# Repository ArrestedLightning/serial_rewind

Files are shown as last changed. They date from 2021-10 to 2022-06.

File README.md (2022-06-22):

# Serial Rewind

Serial Rewind Logo

This project provides an internal serial port to certain PowerPC Macintosh computers that shipped without one built in.  This is accomplished by replacing the internal modem, similar to the GeeThree StealthPort, the Griffin gPort, and Alex Hixon's Jamport.

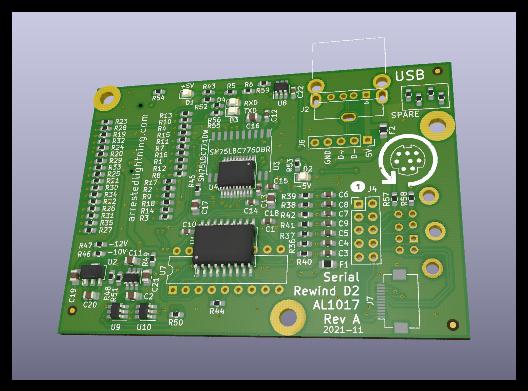
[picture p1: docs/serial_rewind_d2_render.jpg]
Serial Rewind Board render


This project is a work-in-progress.  Any use of the files here is at your own risk.

The goal is to support most PowerPC G3 and G4 machines.  See the README file in the hardware directory for more information on the status of each variant.

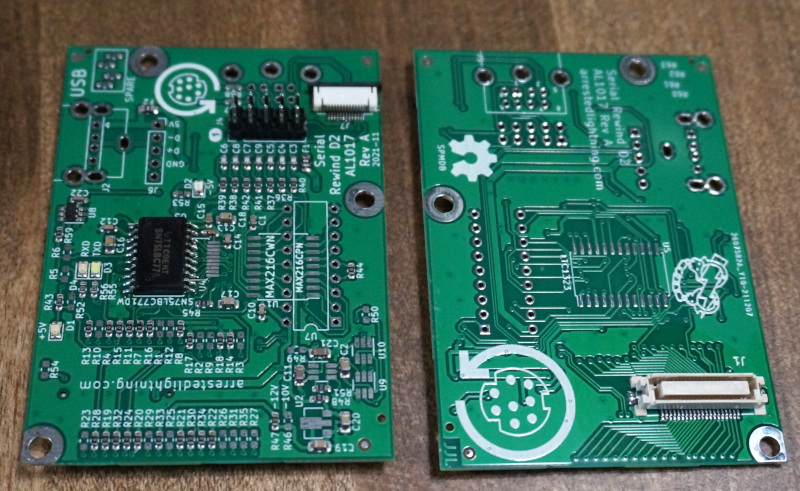
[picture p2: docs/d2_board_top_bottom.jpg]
Serial Rewind Board Picture


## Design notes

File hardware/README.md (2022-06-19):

Serial Rewind Hardware
==========

Serial Rewind Logo

The goal of this project is to eventually support a wide variety of PowerPC Macs.  To do so, a number of different boards are required.  The boards and their statuses are listed below:

|Board|Description|Status|
|-----|---|---|
|d1_g3|Main board ("Dash 1" interface) for tray load iMac G3, B&W Power Mac G3, and PCI Graphics Power Mac G4|Mechanical drawing of board in progress, reverse engineering of schematic not yet started.|
|dash2|Main board ("Dash 2" interface) for a wide variety of Macs: Slot load iMac G3, some iBooks, PowerBook G3, Power Mac G4 & Cube.  All machines except iMac G3 and Cube require an additional board to bring the port out.|Working.  Tested on G4 Cube and G4 MDD.|
|main_mini|Main board for Mac Mini G4, eMac G4, possibly others. | Pinout reverse engineered, schematic in progress. |
|portboard_dt|Port breakout board.  Originally intended for G4 towers.  I believe it would also fit in the iBook G3, but this is not tested. | Electrically functional, layout is a work-in-progress.  The goal was to support both the MDD and earlier G4 machines with the same board, but I don't know if that will be possible. |
|portboard_ffc|Generic port breakout board with flat-flex cable connector. Intended for use with PCI card bracket.| PCB Complete (3D-printed mounting adapter not designed yet)|
|portboard_ribbon|Generic port breakout board with IDC/ribbon cable connector. Intended for use with PCI card bracket.| PCB Complete (3D-printed mounting adapter not designed yet)|| |
|portboard_img4|Port breakout board for iMac G4.  As far as I know, the iMac G4 is the only machine which uses this form factor.| Designed and manufactured, but not yet fit tested. |
|portboard_mdd|Port breakout board for the Power Mac G4 MDD.  This board replaces the MDD's modem port and mounting bracket.  Unfortunately, there's no great way to mount one side of this board.  Since (as far as I know) every MDD comes with a reversible modem port mounting bracket, it seems like it would make more sense to take advantage of that. |Designed and tested.  Eventually this board may be made obsolete by an updated portboard\_dt. |
|portboard_mini|Port breakout board for Mac Mini G4. | Design not started yet.|

All of these boards use components from my [KiCad libraries project](https://github.com/ArrestedLightning/al_kicad_libraries/).  If you work on any of these boards, I would suggest checking out a copy of that project and adding the libraries to your KiCad globals.

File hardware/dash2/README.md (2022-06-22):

# "Dash 2" main board

Dash 2 PCB Render

This is the main board for systems which use a "Dash 2" modem board. This covers a large number of the PowerPC Macs, including the Slot load iMac G3, at least some G3 PowerBooks and iBooks, all Power Mac G4s, and the G4 Cube.  The original Dash 2 modem board supported both an onboard modem port and an external one.  This board also supports both an onboard serial port and an external one.  As far as I know, the onboard port was only used on the slot load iMac G3s and the G4 Cube.  I have tested the onboard port on a G4 cube and it fits perfectly;  I have not yet had the chance to test on an iMac.  All other machines will require an external port breakout board to get the serial port out.

The board is designed around the use of vintage GeoPort chips.  Back in the day, several different chips with roughly equivalent functionality were produced by different manufacturers, but they have all been out of production for years.  At the moment, they seem to be relatively easy to obtain, but that may not necessarily be the case going forward.  Therefore, this board has been designed to support multiple different chips.  All of these vintage chips will require a -5V power supply.  Some can generate their own -5V supply, others require an external -5V supply.  Some Macs provide a negative supply which can be used to produce this; others only provide a positive supply which will then need to be inverted.  This technique will also work on Macs that provide a negative supply and is generally preferred for maximum compatibility.  The board supports a number of different voltage and chip combinations by populating different voltage regulator ICs and jumpers.

The choice to use vintage ICs was a deliberate one; their use of a negative supply is significant.  Although it is possible to produce a working RS-422 serial port using modern ICs (as done in the Jamport), the Mac serial port is actually a unique RS-422/RS232 hybrid design that doesn't really have a modern equivalent as far as I can tell.  Without a negative supply, the voltage output will only be 0-5V in RS232 mode.  While this will work with many recent RS-232 devices, there are a number of vintage devices which really only work well if the RS-232 signal levels can swing negative.  Therefore, for maximum compatibility with vintage devices, there really is no substitute for period-correct transceiver ICs.

The Dash 2 connector also provides signals for a USB port.  This board breaks those signals out to a standard USB type A port, which can be mounted horizontally or vertically.  This could be used (for example) for an internal flash drive or Bluetooth adapter.

More information on possible configurations is detailed on the schematic.  Feel free to open an issue if anything is unclear.

Serial Rewind Board Dash 2 Board Top & Bottom

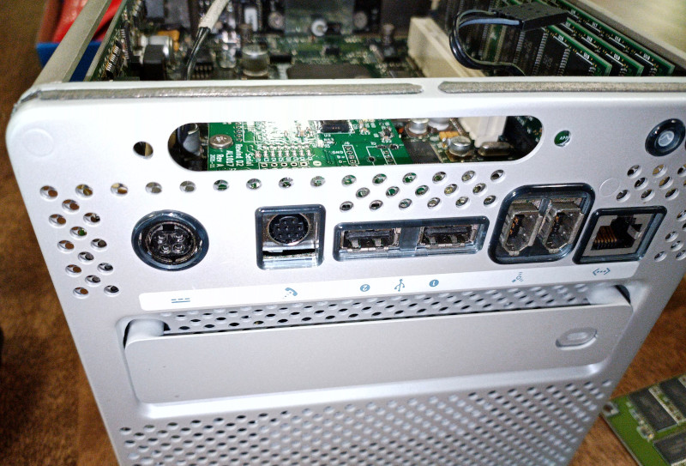
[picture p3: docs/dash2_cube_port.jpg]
Serial Rewind Board Installed in G4 Cube


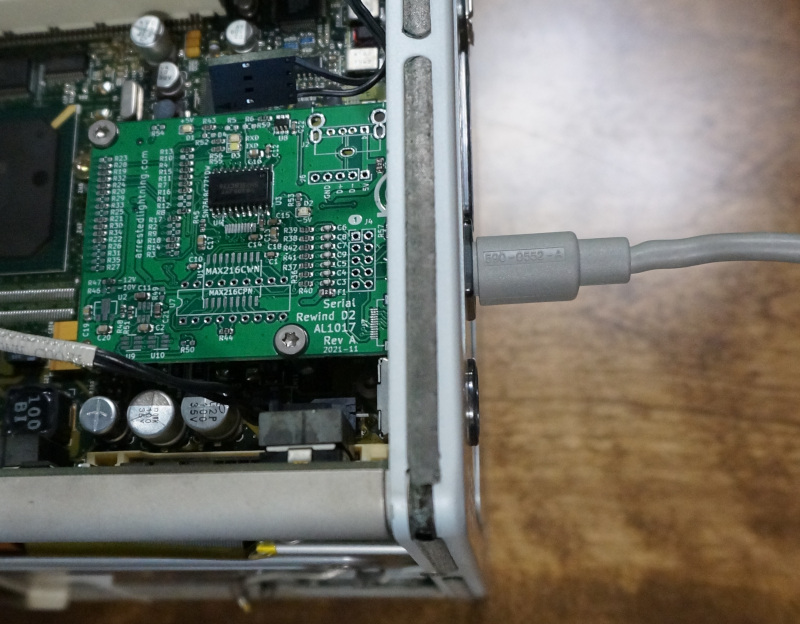
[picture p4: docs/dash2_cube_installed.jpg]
Serial Rewind Board Installed in G4 Cube


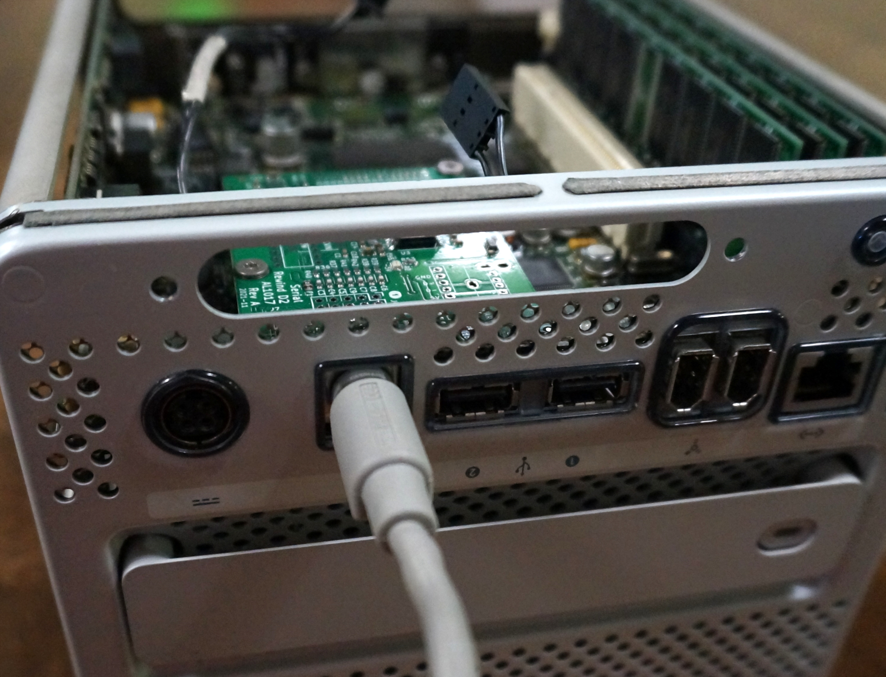
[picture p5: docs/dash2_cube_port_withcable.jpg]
Serial Rewind Board Installed in G4 Cube


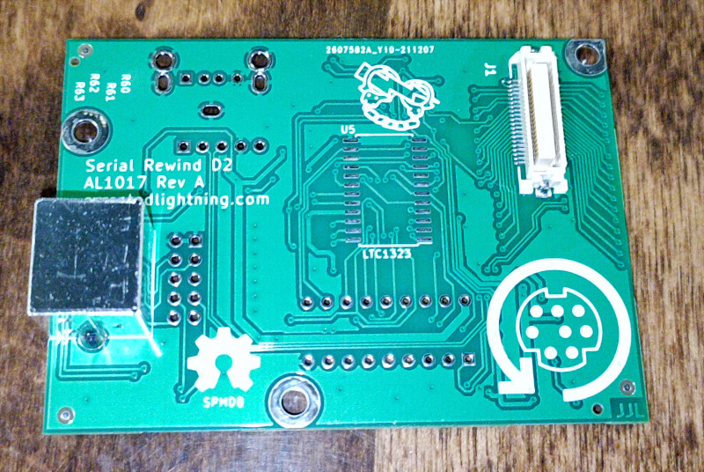
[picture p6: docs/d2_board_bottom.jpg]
Serial Rewind Board Dash 2 Bottom With Onboard Serial Port


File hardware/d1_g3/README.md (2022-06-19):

# "Dash 1" main board

This is the main board for systems which use a "Dash 1" modem board.  As far as I know, this is only the tray-load iMac G3, the Blue & White Power Mac G3, and the PCI Graphics Power Mac G4.  All of these machines have the port integrated in the main board, so a port breakout board is not required.  However, the tower systems will probably require an extension board of some kind to connect to the logic board.

This board is very much a work in progress.  I have not currently done much on it yet beyond measuring the outline used for the port mounting face on the iMac G3.  However, I do have a modem to reverse engineer and machine to test with; the plan is still to finish this at some point.

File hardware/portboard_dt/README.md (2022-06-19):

# Portboard DT
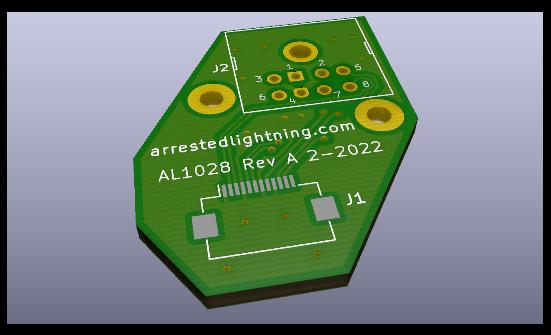
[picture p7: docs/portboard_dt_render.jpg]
Portboard DT PCB Render


This is a simple breakout board originally designed for "desktop" machines (hence the name).  However, I believe this board is also the correct form factor for certain iBook G3 models, and may be useful for others as well.  The intention was for this to be useful for both the Mirrored Drive Door (MDD) as well as earlier G4 desktop machines, however, their stock modem brackets are slightly different in a way that apparently makes this difficult.  I'm still working on a solution for this.

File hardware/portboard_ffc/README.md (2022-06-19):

# Portboard FFC
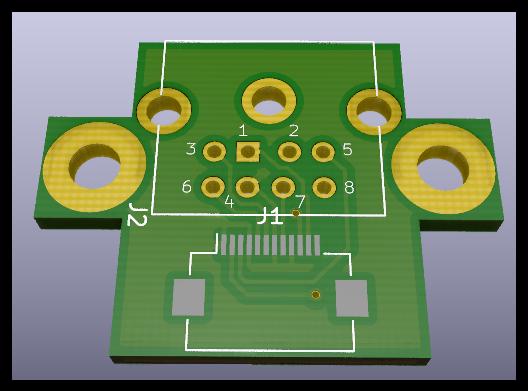
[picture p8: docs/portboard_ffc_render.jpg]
Portboard FFC PCB Render


This is a simple breakout board designed to use a a flat-flex cable for connection to the main board.  This is not designed to fit in any specific machine; instead, the intention was it could be used on a PCI bracket.  (A 3D-printed mounting bracket would be required, but has not been designed yet.)  I would generally recommend using one of the machine-specfic port breakouts instead when possible, but removing the original modem port non-destructively is not the most straightforward on some machines.  A PCI bracket may be preferred for users who want to keep their machines as close to stock as possible.

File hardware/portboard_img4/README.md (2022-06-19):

# Portboard IMG4
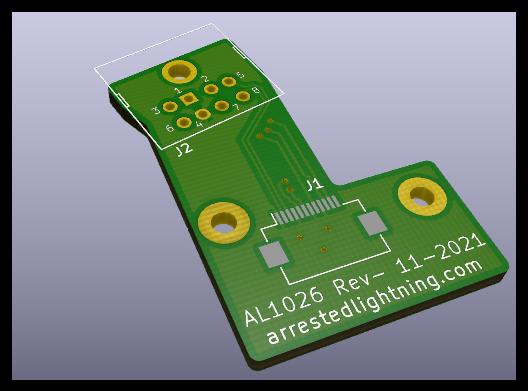
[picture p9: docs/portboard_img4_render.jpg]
Portboard IMG4 PCB Render


This is a simple breakout board designed specifically for the iMac G4.  As far as I know, the iMac G4 is the only machine which used this form factor modem port board.  This board was designed based on measurements from an original board, but has not yet been fit-tested in an actual machine.  I can therefore make no guarantees about its usability.

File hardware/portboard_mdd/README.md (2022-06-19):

# Portboard MDD
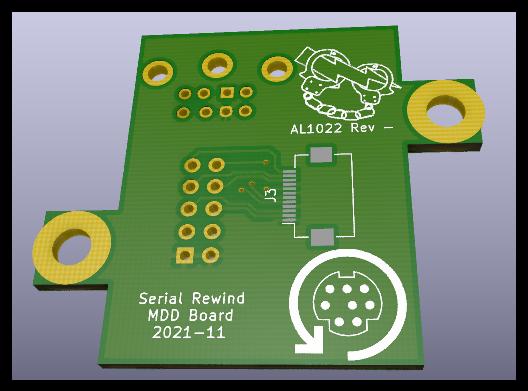
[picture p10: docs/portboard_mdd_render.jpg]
Portboard MDD PCB Render


This is a simple breakout board designed specifically for the Mirrored Drive Door (MDD) Power Mac G4.  This was an experiment to see if there was an easy way to take advantage of the existing mounting points in the MDD to design a PCB-only replacement for the modem port.  However, it didn't end up being a great solution.  There is only one usable mounting hole built into the case, and the board tends to rotate when plugging in a serial device. I wasn't able to find a great way to anchor the other side of the board besides using a zip tie.  The stock modem port bracket has tabs that lock into the case, but they are too small to realistically 3D print a replacement.  I also had to use a washer to space the board up to the right height.
Given that the stock modem port bracket is reversible to blank off the port if no modem was originally included, I believe that all MDD machines came with a usable bracket.  Therefore, this board is probably of limited use in the vast majority of cases.  The optimum solution going forward will probably be to make an updated portboard_dt design which supports the use of the stock modem bracket.

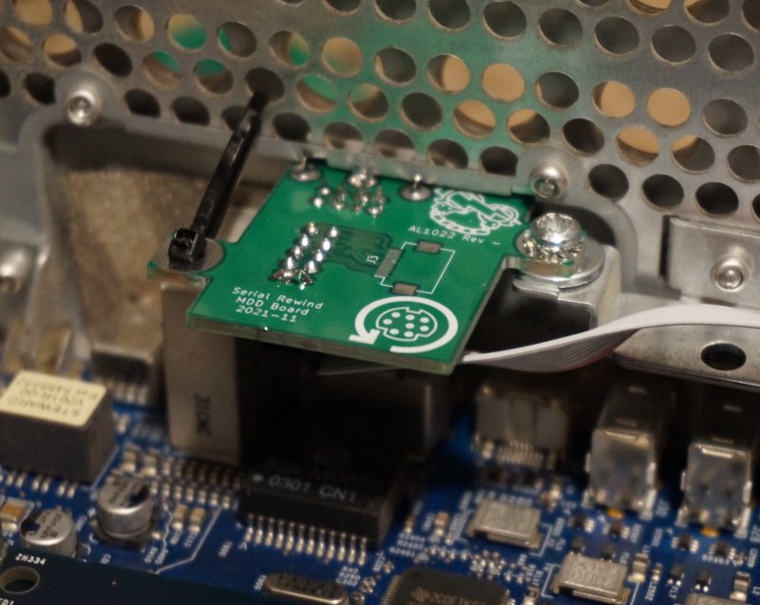
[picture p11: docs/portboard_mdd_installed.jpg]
Portboard MDD PCB Photo


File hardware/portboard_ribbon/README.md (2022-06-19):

# Portboard Ribbon
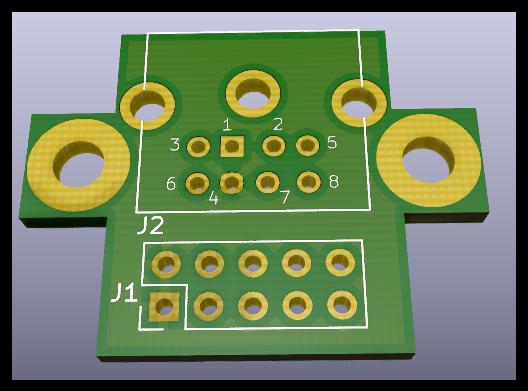
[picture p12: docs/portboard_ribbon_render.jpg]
Portboard Ribbon PCB Render


This is a simple breakout board designed to use a pin header connection to a IDC connector on a ribbon cable.  This is not designed to fit in any specific machine; instead, the intention was it could be used on a PCI bracket.  (A 3D-printed mounting bracket would be required, but has not been designed yet.)  I would generally recommend using one of the machine-specfic port breakouts instead when possible, but removing the original modem port non-destructively is not the most straightforward on some machines.  A PCI bracket may be preferred for users who want to keep their machines as close to stock as possible.

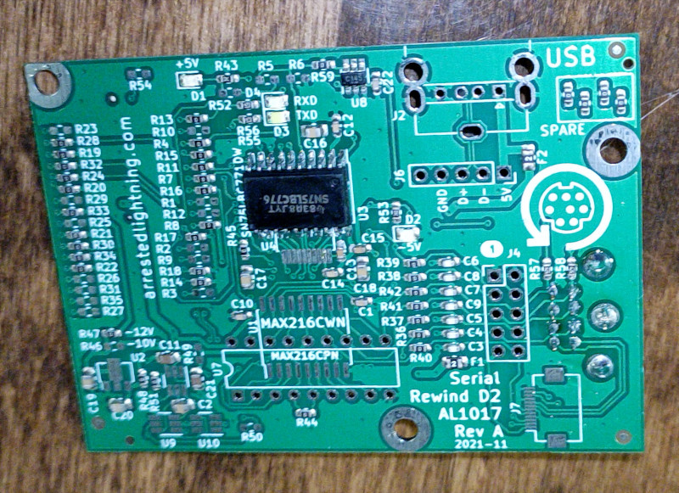
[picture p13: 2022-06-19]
docs/d2_board_top.jpg

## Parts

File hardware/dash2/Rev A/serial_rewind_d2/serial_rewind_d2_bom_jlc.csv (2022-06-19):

Comment | Designator | Footprint | LCSC Part #
1uF/16V | C2 | C_0805_2012Metric_Pad1.18x1.45mm_HandSolder | C28323
100pF | C4,C6,C8,C5,C7,C3,C9 | C_0603_1608Metric_Pad1.08x0.95mm_HandSolder | C14858
2.2uF/16V | C11,C21 | C_0805_2012Metric_Pad1.18x1.45mm_HandSolder | C49217
0.33uF/16V | C18,C17,C16,C19,C20 | C_0805_2012Metric_Pad1.18x1.45mm_HandSolder | C1740
0.1uF | C22,C13,C10,C14,C12,C1,C15 | C_0603_1608Metric_Pad1.08x0.95mm_HandSolder | C14663
GREEN | D1 | LED_0805_2012Metric | C2297
RED | D2 | LED_0805_2012Metric | C84256
WHITE | D3 | LED_0805_2012Metric | C34499
BLUE | D4 | LED_0805_2012Metric | C2293
Polyfuse | F2,F1 | Fuse_0805_2012Metric_Pad1.15x1.40mm_HandSolder | C70057
0 | R28,R32,R24,R33,R30,R34,R13,R4,R11,R7,R8,R19,R20,R21,R22,R15,R16,R17,R18,R14,R37,R38,R39,R40,R41,R36,R42,R59,R62,R60,R63,R61,R44,R45,R51,R47,R48 | R_0603_1608Metric_Pad0.98x0.95mm_HandSolder | C21189
10K | R43,R53 | R_0603_1608Metric_Pad0.98x0.95mm_HandSolder | C25804
4K7 | R55,R56 | R_0603_1608Metric_Pad0.98x0.95mm_HandSolder | C23162
470K | R57,R58 | R_0603_1608Metric_Pad0.98x0.95mm_HandSolder | C23178
LM2776 | U6 | SOT-23-6_Handsoldering | C840110
SN74LVC2G14DBVR | U8 | SOT-23-6_Handsoldering | C12401
MAX1721 | U9 | SOT-23-6_Handsoldering | C242523
LM2664 | U10 | SOT-23-6_Handsoldering | C840095

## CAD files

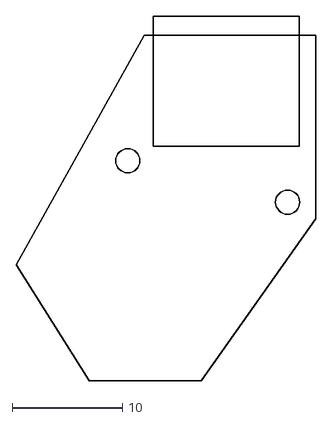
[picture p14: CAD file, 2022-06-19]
hardware/portboard_dt/RevA/Mechanical/Board Outline-BodySketch.dxf
27.2 x 33.1

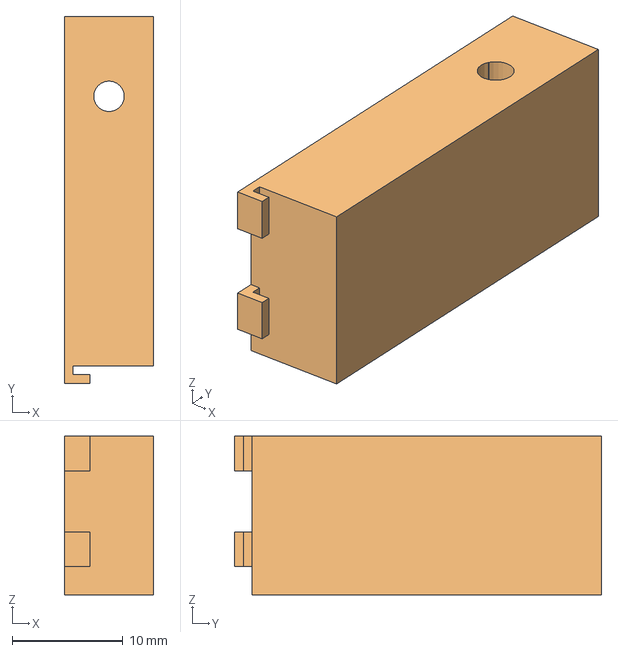
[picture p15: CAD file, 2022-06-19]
hardware/portboard_mdd/Rev-/Mechanical/Retention Bracket.FCStd
8.05 x 33.1 x 14.3 mm
Pad002 (Meshed)

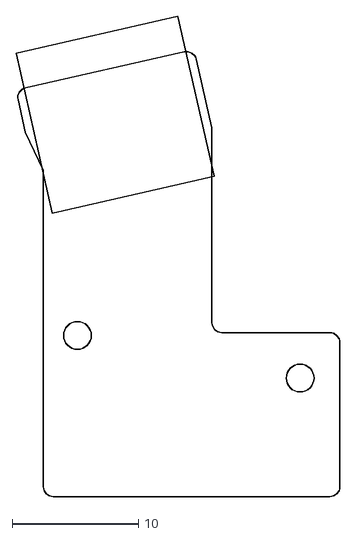
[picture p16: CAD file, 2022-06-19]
hardware/portboard_img4/Rev-/Mechanical/Board Outline-BodySketch.dxf
25.7 x 38.1

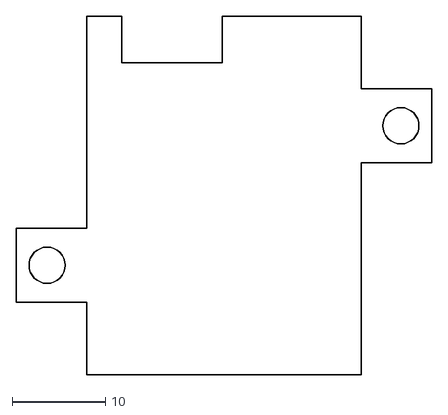
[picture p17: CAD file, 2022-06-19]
hardware/portboard_mdd/Rev-/Mechanical/Board Outline-BodySketch.dxf
44.6 x 38.5

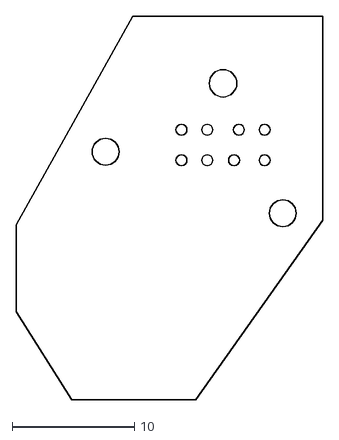
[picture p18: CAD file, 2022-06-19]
hardware/portboard_dt/RevA/Mechanical/portboard dt test.dxf
25.1 x 31.4

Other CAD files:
docs/logo_sketch_constrained.FCStd
hardware/d1_g3/Rev-/Mechnical/Mounting Face.FCStd
hardware/portboard_dt/Rev-/Mechanical/Board Outline.FCStd
hardware/portboard_img4/Rev-/Mechanical/Board Outline.FCStd
hardware/portboard_dt/RevA/Mechanical/Board Outline.FCStd
hardware/portboard_mdd/Rev-/Mechanical/Board Outline.FCStd

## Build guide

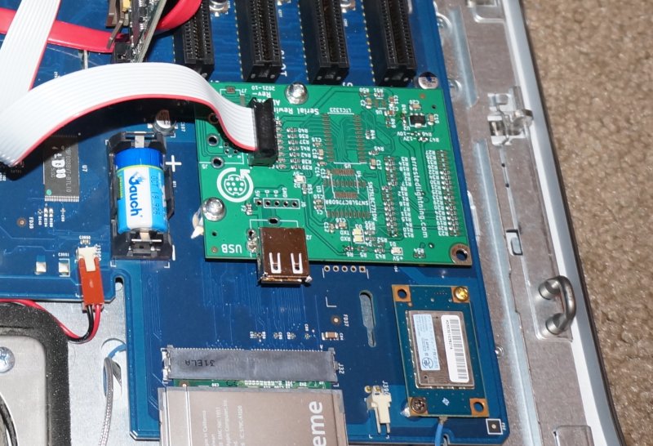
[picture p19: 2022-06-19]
docs/dash2_installed.jpg

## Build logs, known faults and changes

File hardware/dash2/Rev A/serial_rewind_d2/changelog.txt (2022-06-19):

Rev - to Rev A:
  Changed 10-pin header to male version (physical pinout stays the same)
  Flipped mini-DIN connector to back side of board
  Slight change to logo
  Changed default jumper settings to use -12V rail
  Added DIP footprint for MAX216CPN
  Changed default jumper stuffing
  Added inverter on standby line

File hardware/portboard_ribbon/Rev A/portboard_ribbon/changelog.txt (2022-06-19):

Rev - to Rev A
  Changed connector pinout to match main board

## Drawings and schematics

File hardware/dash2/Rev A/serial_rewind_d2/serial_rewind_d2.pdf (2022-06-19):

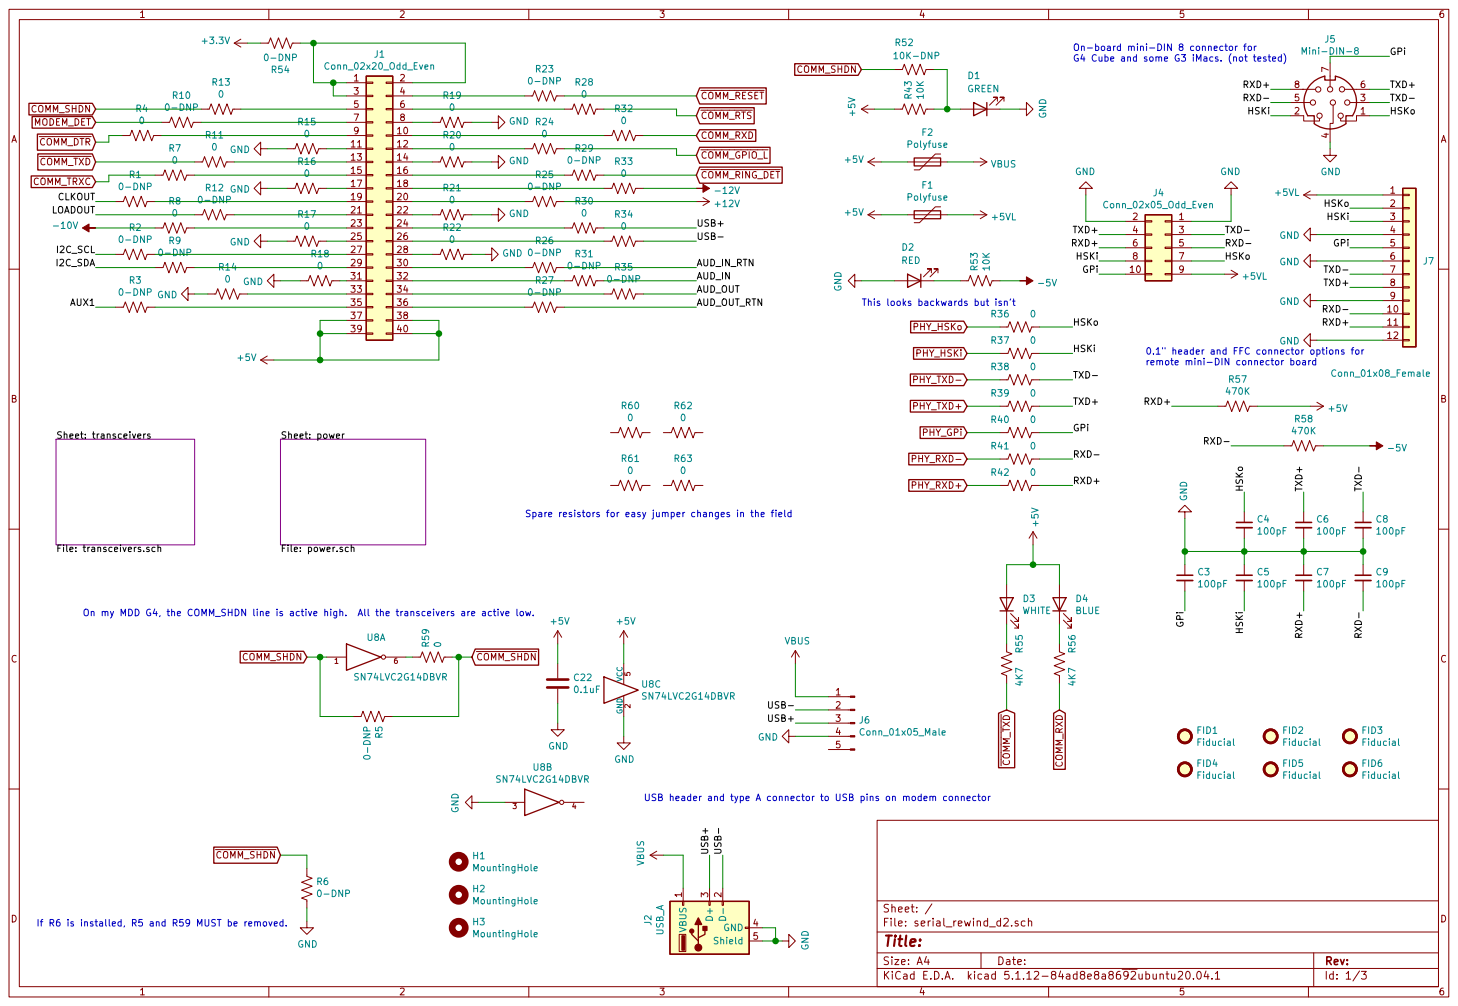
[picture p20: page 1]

remote mini-DIN connector board This looks backwards but isn't

0.1" header and FFC connector options for

Spare resistors for easy jumper changes in the field

If R6 is installed, R5 and R59 MUST be removed. On my MDD G4, the COMM_SHDN line is active high. All the transceivers are active low.

USB header and type A connector to USB pins on modem connector

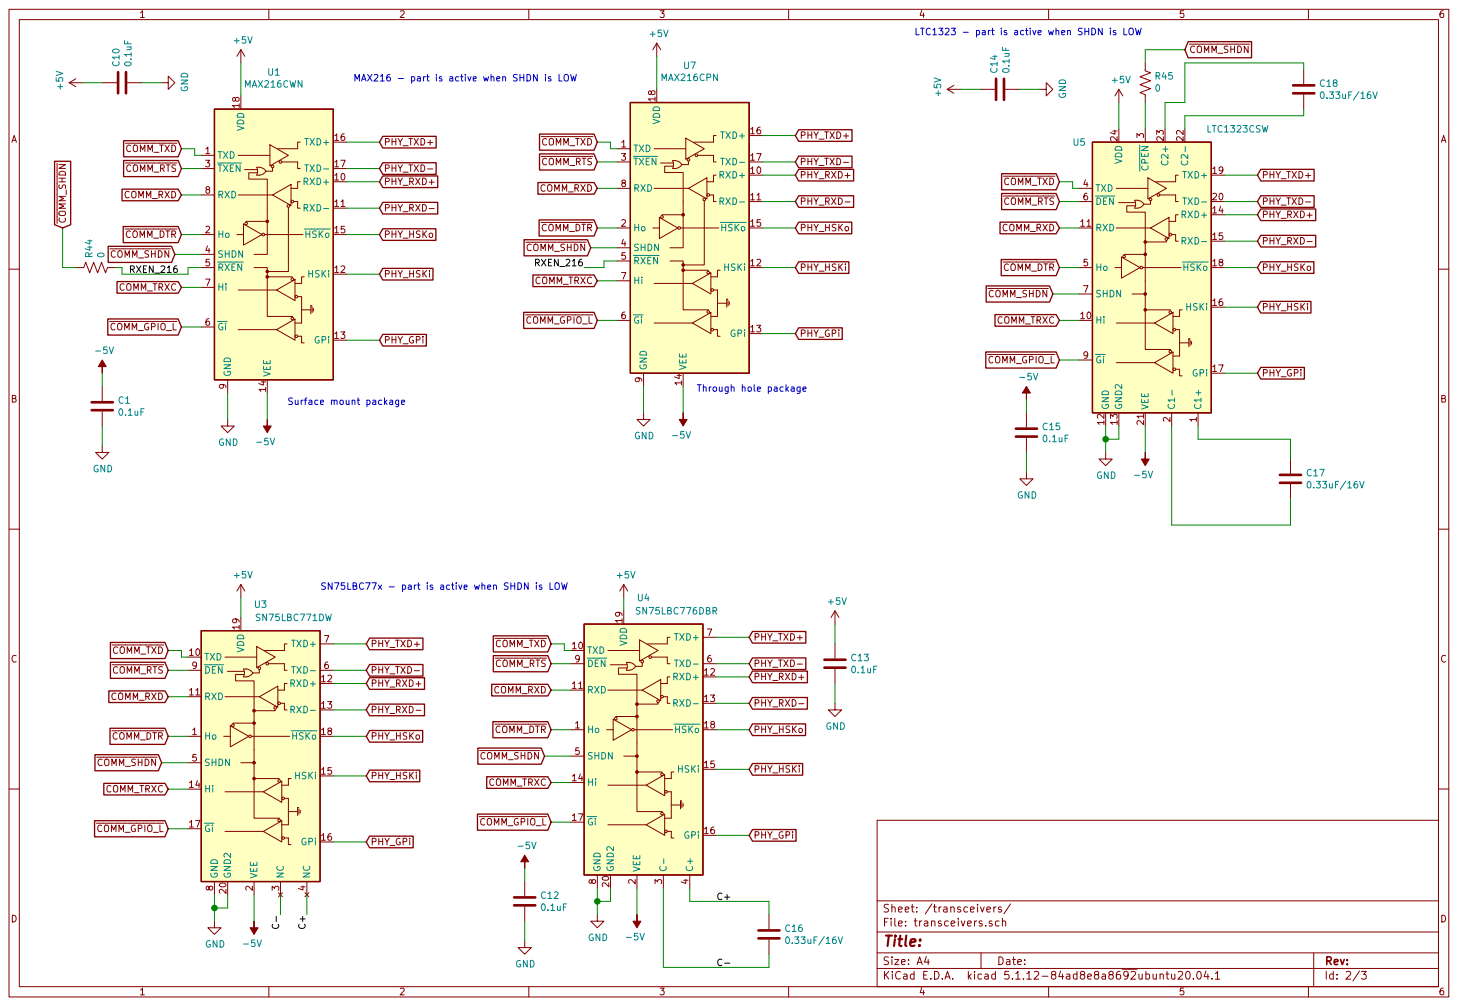
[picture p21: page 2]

LTC1323 - part is active when SHDN is LOW

Id: 2/3 Title: File: transceivers.sch Sheet: /transceivers/ +5V

MAX216 - part is active when SHDN is LOW

3 TXD 4 Ho 5 DEN 6 SHDN 7 Gi 9 U5

1 Hi 10 RXD 11 GND 12 GND2 13 RXD+ 14 RXD- 15 HSKi 16 GPi 17 HSKo 18 TXD+ 19 C1- 2 TXD- 20 VEE 21 C2- 22 C2+ 23 VDD 24 CPEN

SN75LBC77x - part is active when SHDN is LOW
PHY_TXD- PHY_GPi PHY_RXD- PHY_HSKo PHY_HSKi

4 SHDN 5 TXD- 6 TXD+ 7 GND

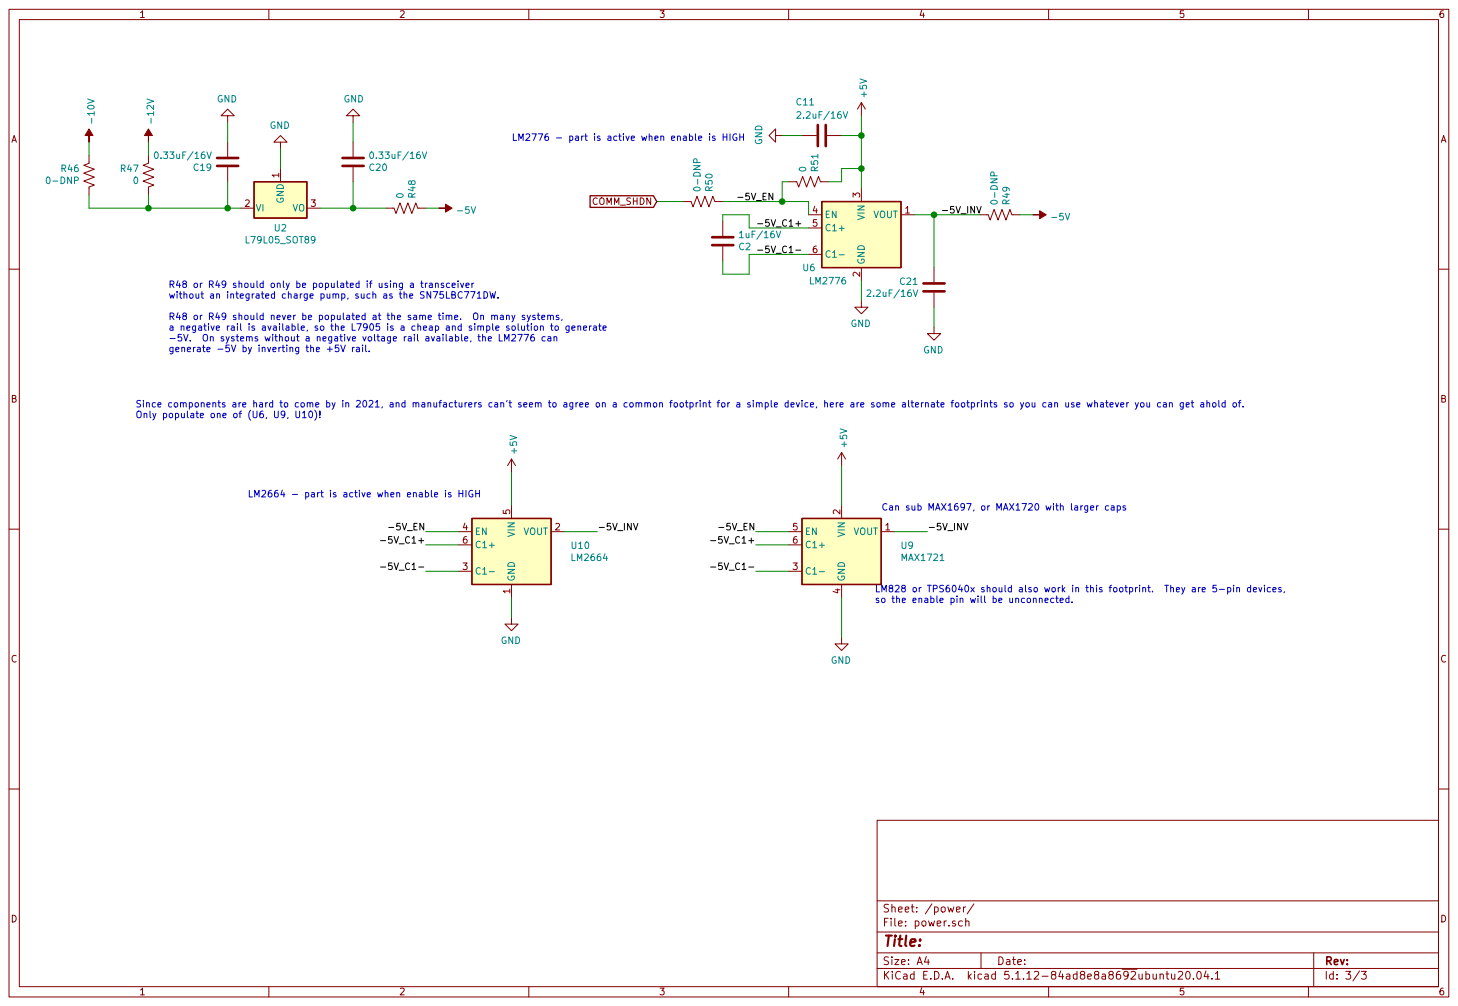
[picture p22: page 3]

LM2776 - part is active when enable is HIGH

R48 or R49 should only be populated if using a transceiver
without an integrated charge pump, such as the SN75LBC771DW.

R48 or R49 should never be populated at the same time. On many systems,
a negative rail is available, so the L7905 is a cheap and simple solution to generate
-5V. On systems without a negative voltage rail available, the LM2776 can
generate -5V by inverting the +5V rail.

Since components are hard to come by in 2021, and manufacturers can't seem to agree on a common footprint for a simple device, here are some alternate footprints so you can use whatever you can get ahold of.
Only populate one of (U6, U9, U10)!

LM2664 - part is active when enable is HIGH

Can sub MAX1697, or MAX1720 with larger caps

LM828 or TPS6040x should also work in this footprint. They are 5-pin devices,
so the enable pin will be unconnected.

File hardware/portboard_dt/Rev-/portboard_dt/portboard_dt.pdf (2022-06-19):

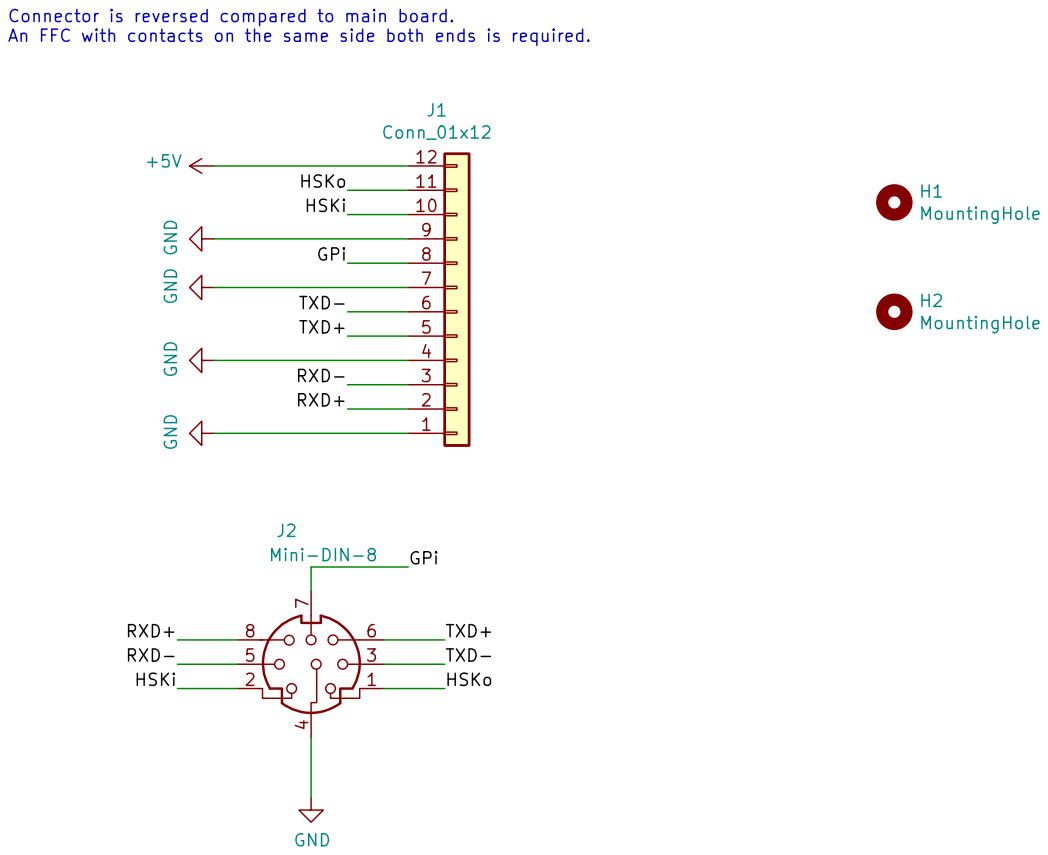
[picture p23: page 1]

An FFC with contacts on the same side both ends is required.

File: portboard_dt.sch Sheet: / GND GND GND GND

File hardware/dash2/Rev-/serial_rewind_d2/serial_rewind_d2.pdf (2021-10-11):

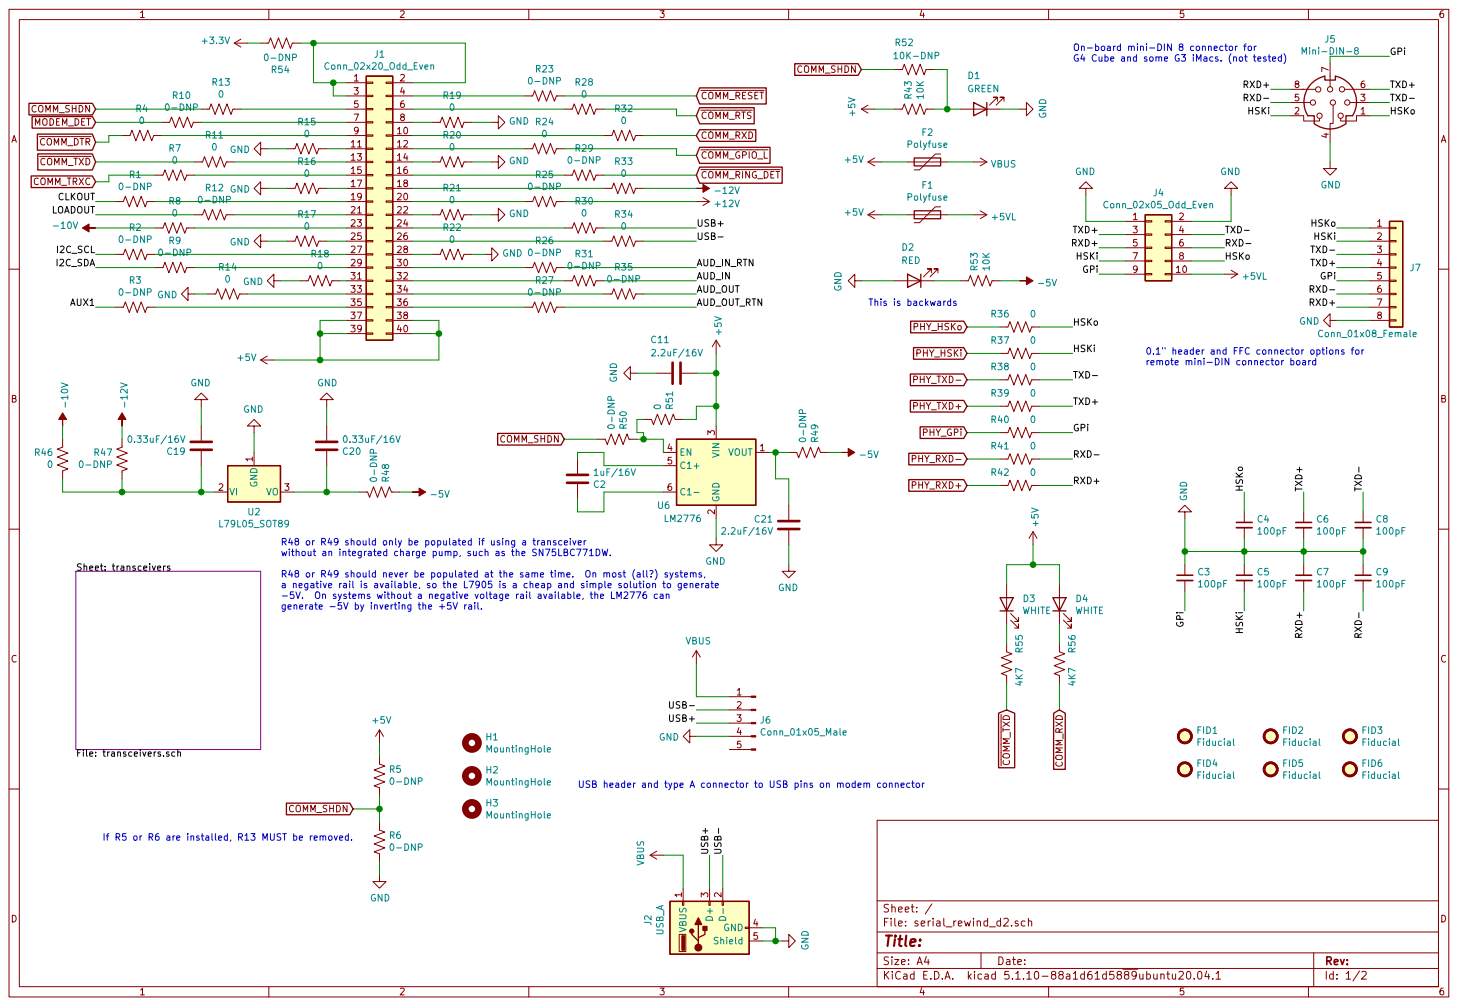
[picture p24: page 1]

On-board mini-DIN 8 connector for G4 Cube and some G3 iMacs. (not tested)

0-DNP GND GND GND GND GND GNDGND

0.1" header and FFC connector options for
remote mini-DIN connector board

R48 or R49 should only be populated if using a transceiver
without an integrated charge pump, such as the SN75LBC771DW.

3 GND 4 Shield 5 J2 USB_A GND GND

R48 or R49 should never be populated at the same time. On most (all?) systems,
a negative rail is available, so the L7905 is a cheap and simple solution to generate
-5V. On systems without a negative voltage rail available, the LM2776 can

If R5 or R6 are installed, R13 MUST be removed.

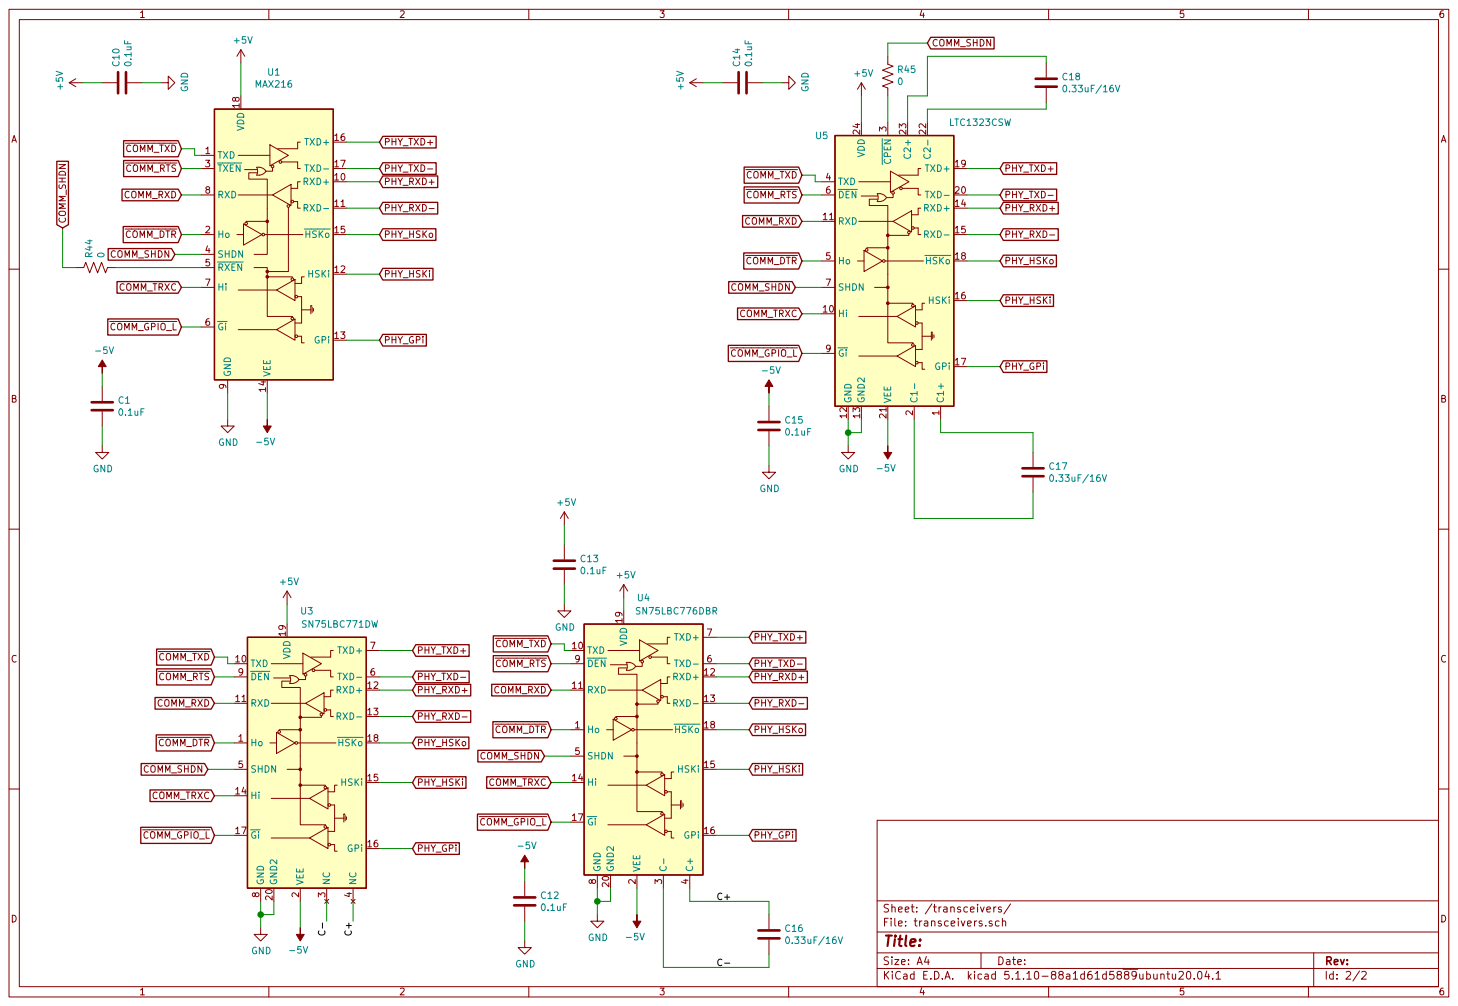
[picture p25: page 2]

Id: 2/2 Title: File: transceivers.sch Sheet: /transceivers/ +5V

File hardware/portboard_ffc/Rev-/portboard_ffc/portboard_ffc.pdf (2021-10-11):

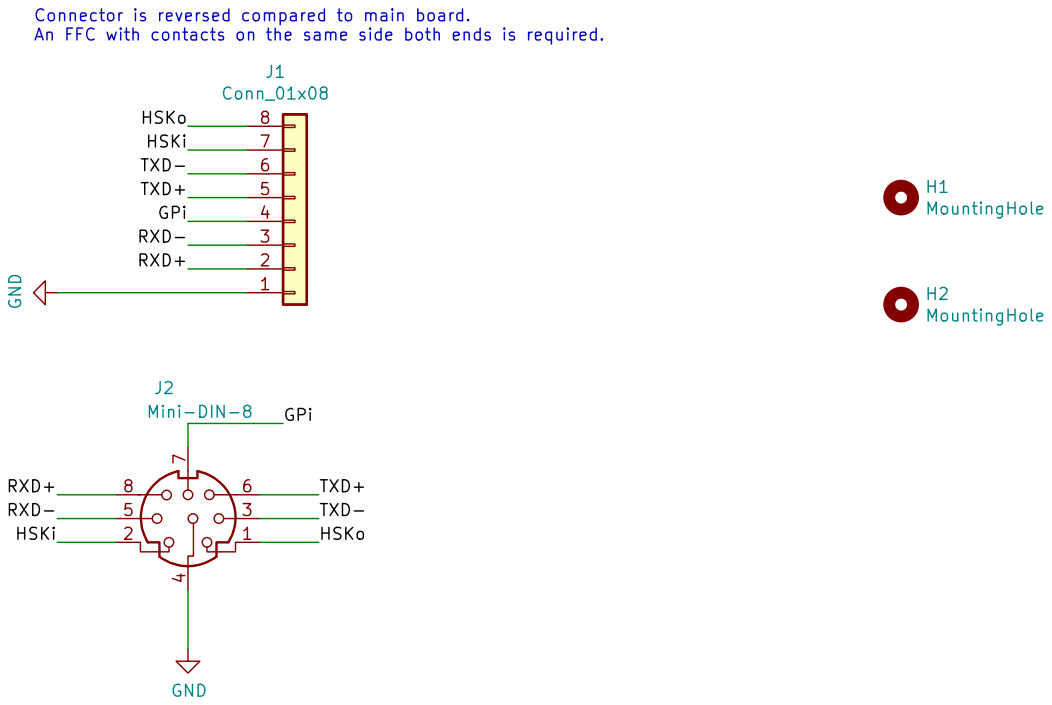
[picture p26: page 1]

An FFC with contacts on the same side both ends is required.

File: portboard_ffc.sch Sheet: / GND

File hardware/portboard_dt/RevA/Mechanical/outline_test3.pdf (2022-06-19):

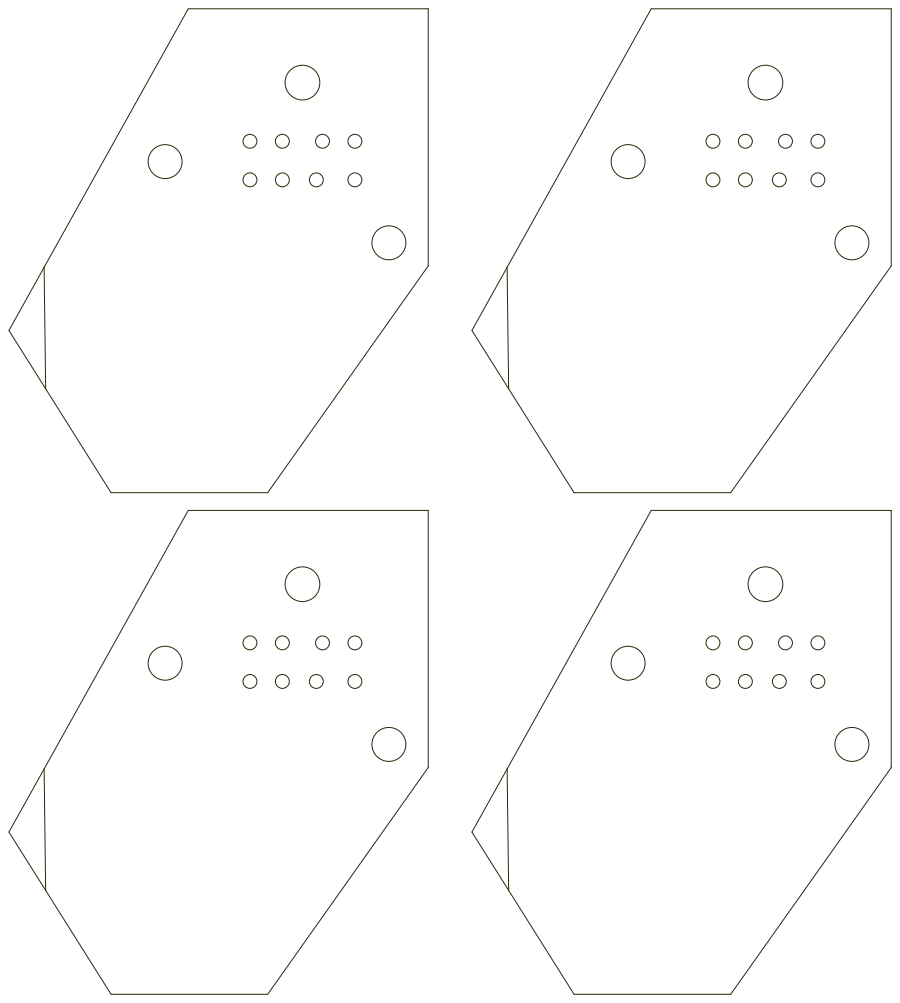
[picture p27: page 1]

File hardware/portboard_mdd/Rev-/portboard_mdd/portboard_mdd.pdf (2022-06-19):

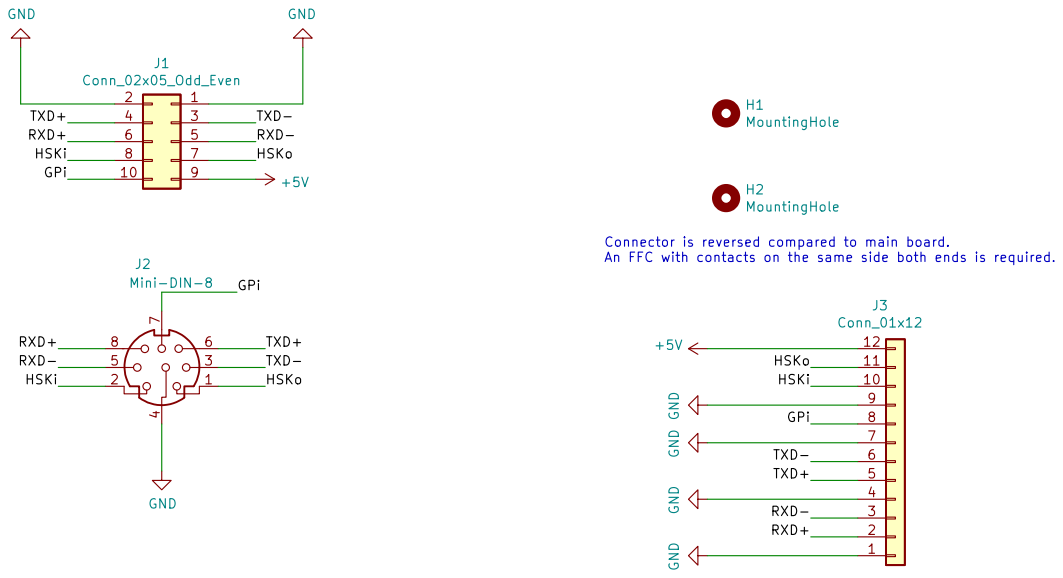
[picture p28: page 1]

An FFC with contacts on the same side both ends is required.

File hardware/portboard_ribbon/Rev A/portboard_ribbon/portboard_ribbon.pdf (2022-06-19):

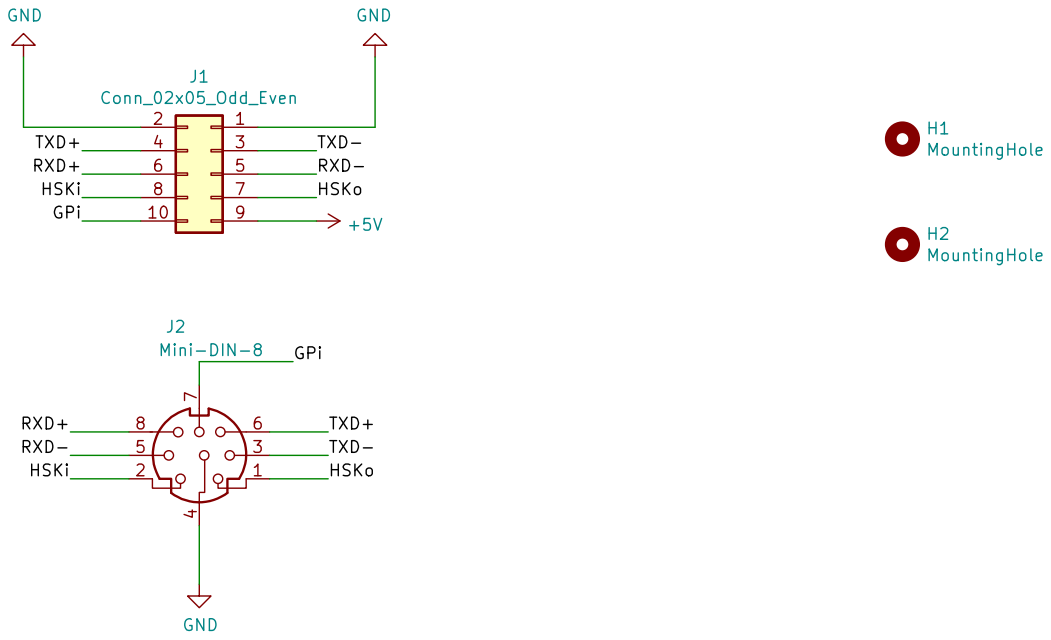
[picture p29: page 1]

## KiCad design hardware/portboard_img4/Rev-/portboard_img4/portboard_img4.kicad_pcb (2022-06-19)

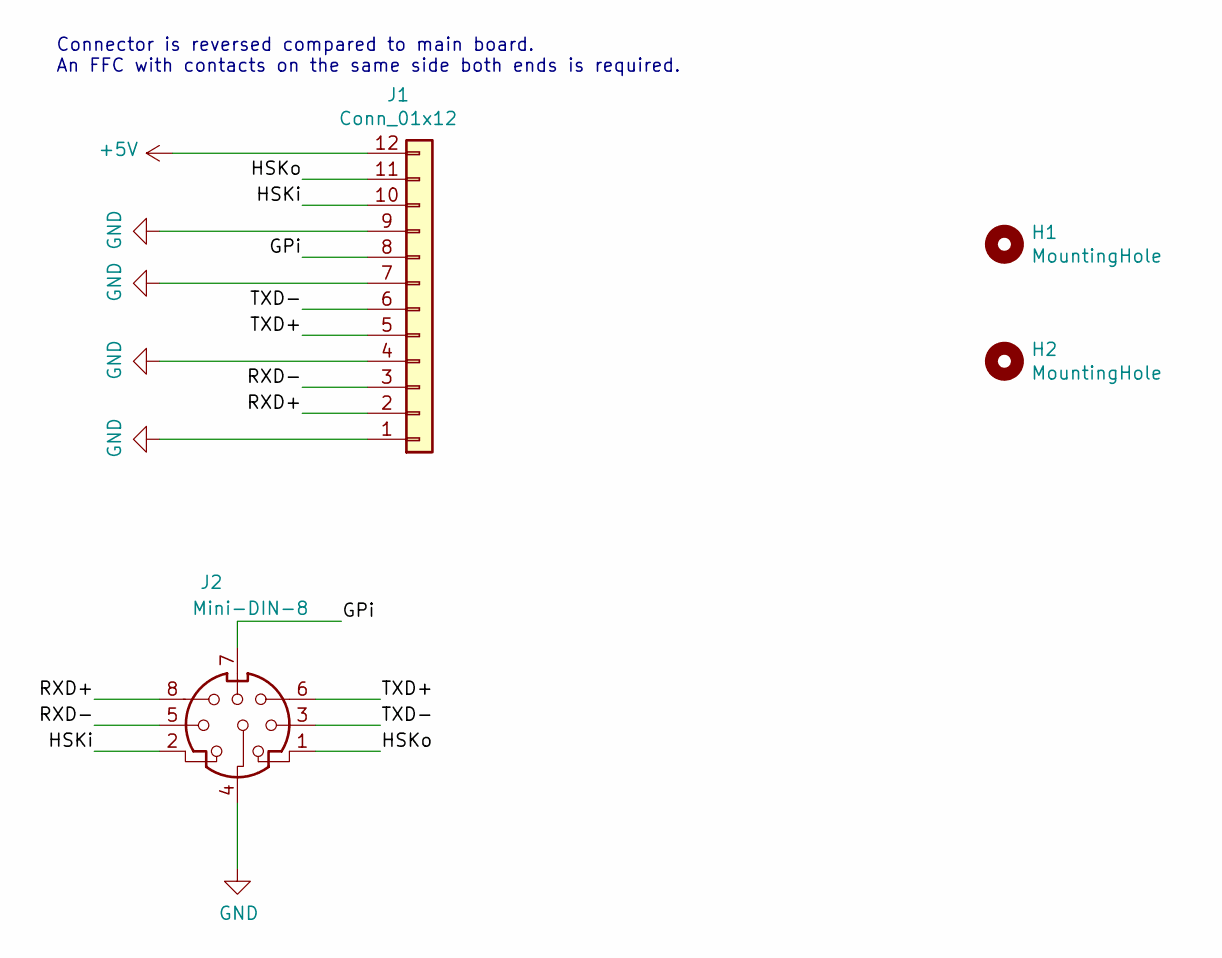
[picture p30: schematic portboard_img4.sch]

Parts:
H1, H2: MountingHole; MountingHole_2.2mm_M2_Pad
J1: Conn_01x12; Hirose_FH12-12S-0.5SH_1x12-1MP_P0.50mm_Horizontal
J2: Mini-DIN-8; MINI_DIN8-1H

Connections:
+5V: J1.12
/GPi: J1.8, J2.7
/HSKi: J1.10, J2.2
/HSKo: J1.11, J2.1
/RXD+: J1.2, J2.8
/RXD-: J1.3, J2.5
/TXD+: J1.5, J2.6
/TXD-: J1.6, J2.3
GND: J1.1, J1.4, J1.7, J1.9, J2.4

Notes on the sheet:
Connector is reversed compared to main board. An FFC with contacts on the same side both ends is required.

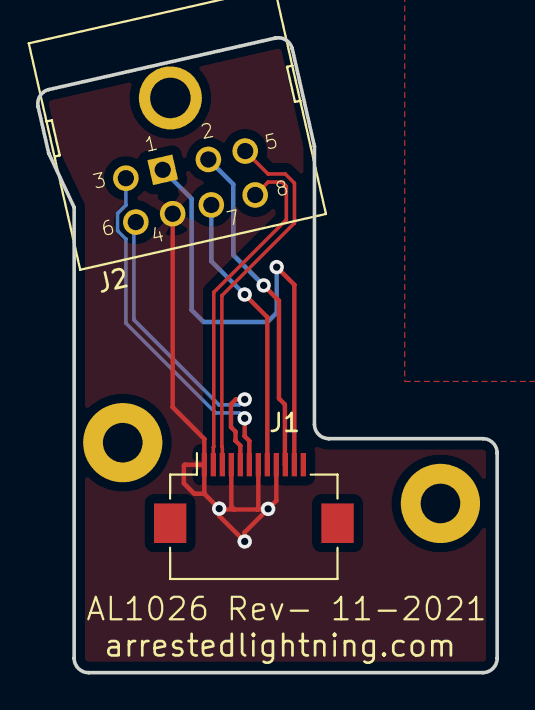
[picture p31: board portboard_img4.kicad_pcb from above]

Board: 2 copper layers, 25.5 x 35.3 mm, 4 parts (0 on the bottom side), 8 nets.

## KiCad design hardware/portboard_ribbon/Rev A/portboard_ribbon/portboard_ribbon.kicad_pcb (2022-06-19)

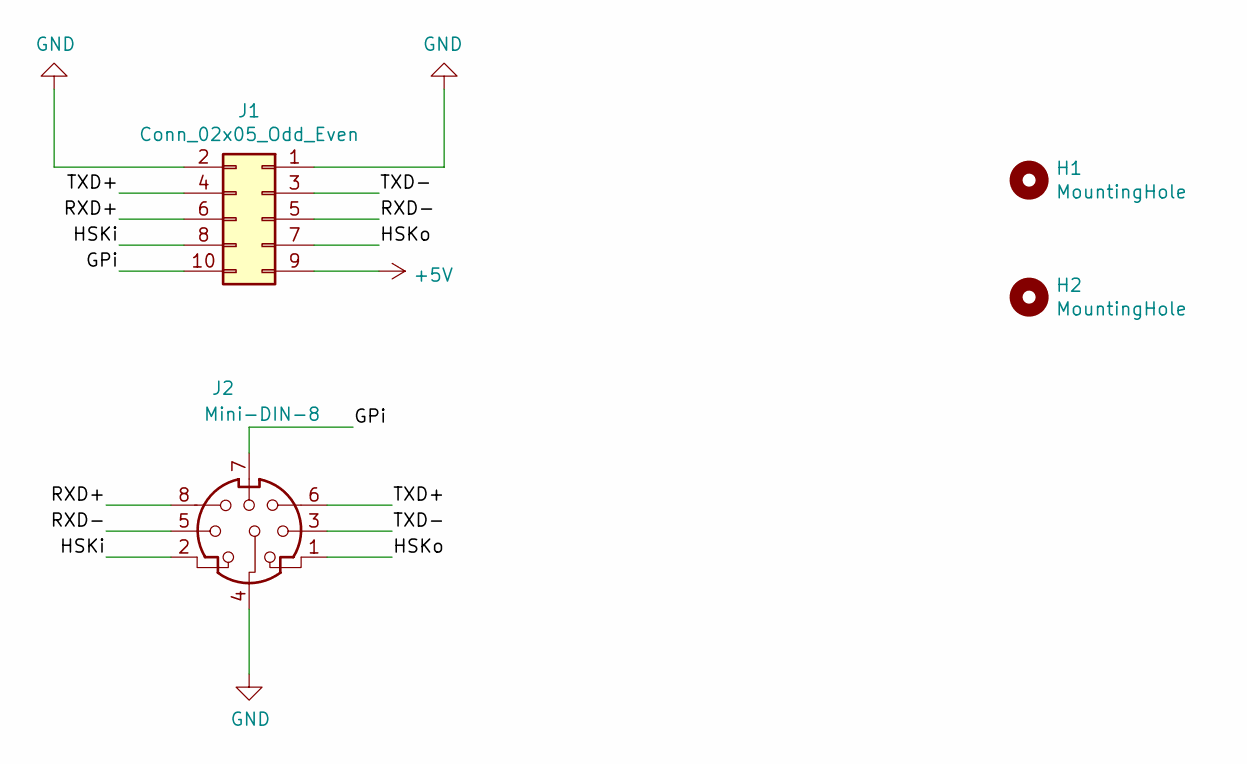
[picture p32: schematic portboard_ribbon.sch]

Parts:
H1, H2: MountingHole; MountingHole_3.2mm_M3_Pad
J1: Conn_02x05_Odd_Even; PinHeader_2x05_P2.54mm_Vertical
J2: Mini-DIN-8; MINI_DIN8

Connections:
+5V: J1.9
/GPi: J1.10, J2.7
/HSKi: J1.8, J2.2
/HSKo: J1.7, J2.1
/RXD+: J1.6, J2.8
/RXD-: J1.5, J2.5
/TXD+: J1.4, J2.6
/TXD-: J1.3, J2.3
GND: J1.1, J1.2, J2.4

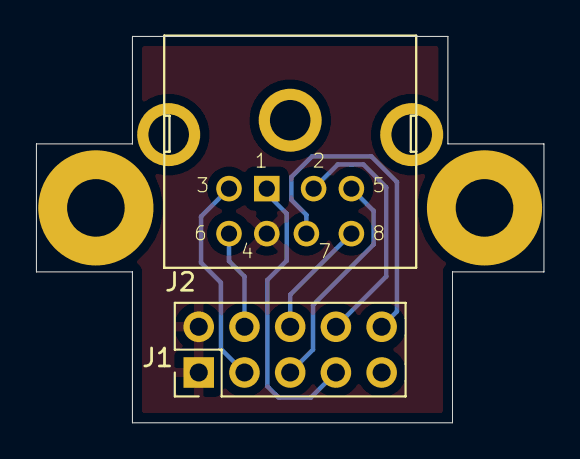
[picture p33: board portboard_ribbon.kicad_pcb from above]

Board: 2 copper layers, 28.2 x 21.5 mm, 4 parts (0 on the bottom side), 8 nets.

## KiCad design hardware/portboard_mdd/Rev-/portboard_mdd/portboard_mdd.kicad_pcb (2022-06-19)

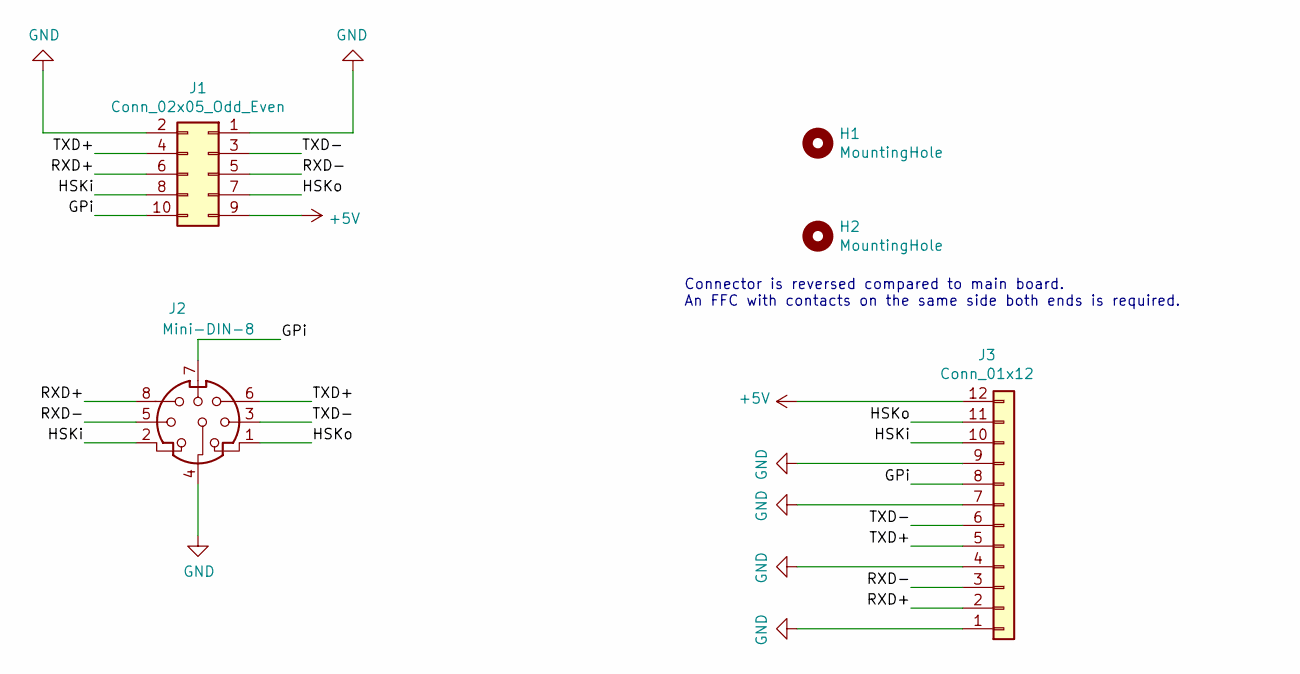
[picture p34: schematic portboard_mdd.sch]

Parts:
H1, H2: MountingHole; MountingHole_4mm_Pad
J1: Conn_02x05_Odd_Even; PinHeader_2x05_P2.54mm_Vertical
J2: Mini-DIN-8; MINI_DIN8
J3: Conn_01x12; Hirose_FH12-12S-0.5SH_1x12-1MP_P0.50mm_Horizontal

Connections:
+5V: J1.9, J3.12
/GPi: J1.10, J2.7, J3.8
/HSKi: J1.8, J2.2, J3.10
/HSKo: J1.7, J2.1, J3.11
/RXD+: J1.6, J2.8, J3.2
/RXD-: J1.5, J2.5, J3.3
/TXD+: J1.4, J2.6, J3.5
/TXD-: J1.3, J2.3, J3.6
GND: J1.1, J1.2, J2.4, J3.1, J3.4, J3.7, J3.9

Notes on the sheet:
Connector is reversed compared to main board. An FFC with contacts on the same side both ends is required.

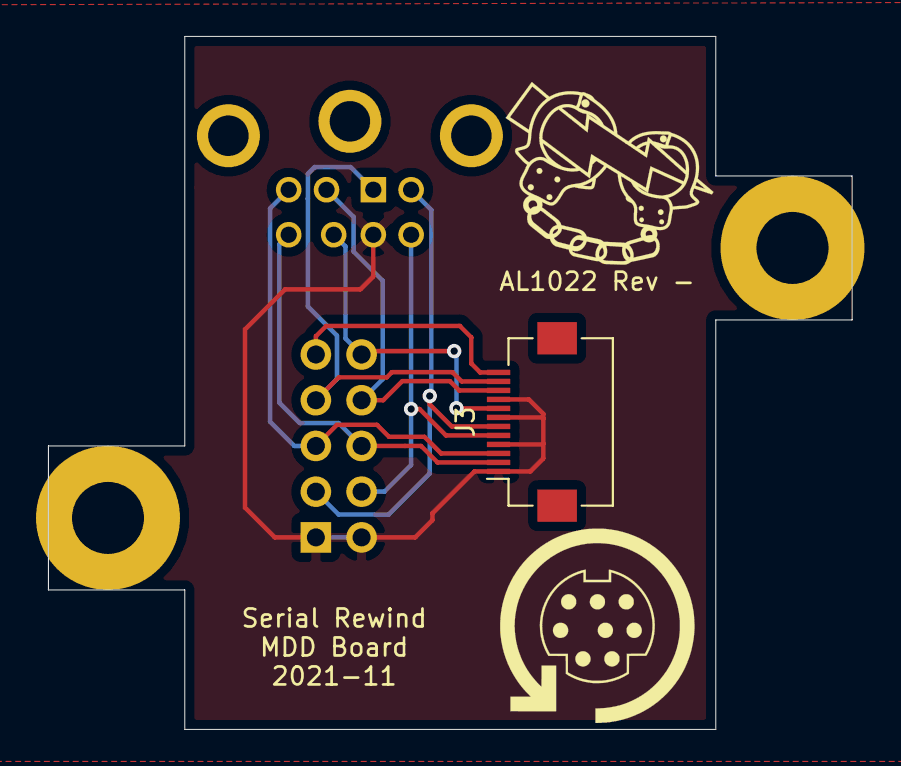
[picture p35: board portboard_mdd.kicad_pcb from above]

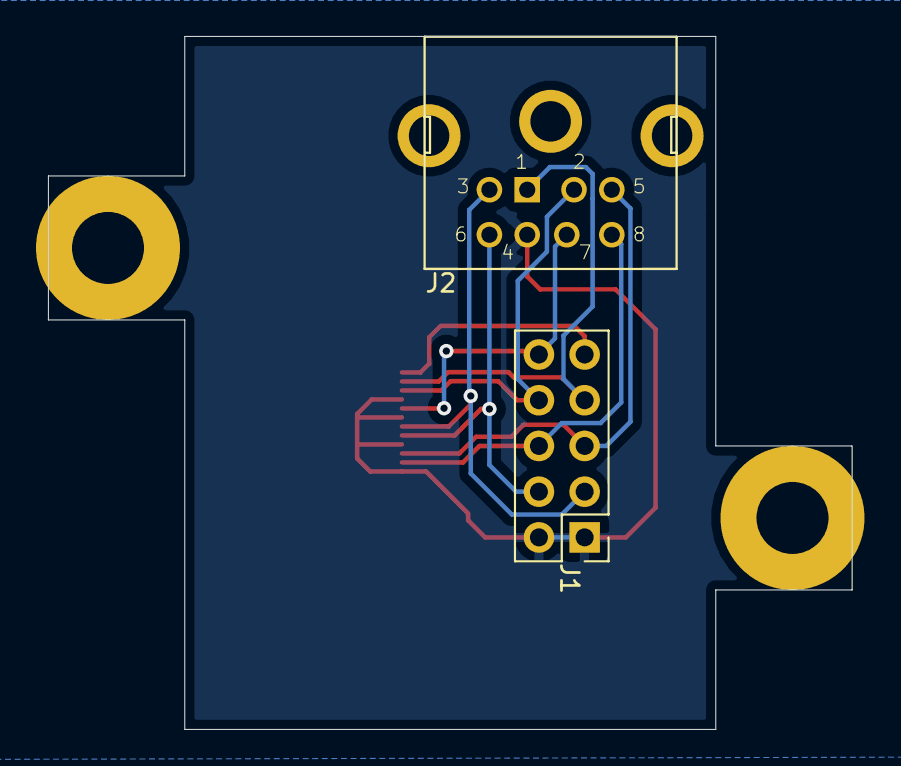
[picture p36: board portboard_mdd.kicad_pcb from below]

Board: 2 copper layers, 44.6 x 38.5 mm, 5 parts (2 on the bottom side), 9 nets.

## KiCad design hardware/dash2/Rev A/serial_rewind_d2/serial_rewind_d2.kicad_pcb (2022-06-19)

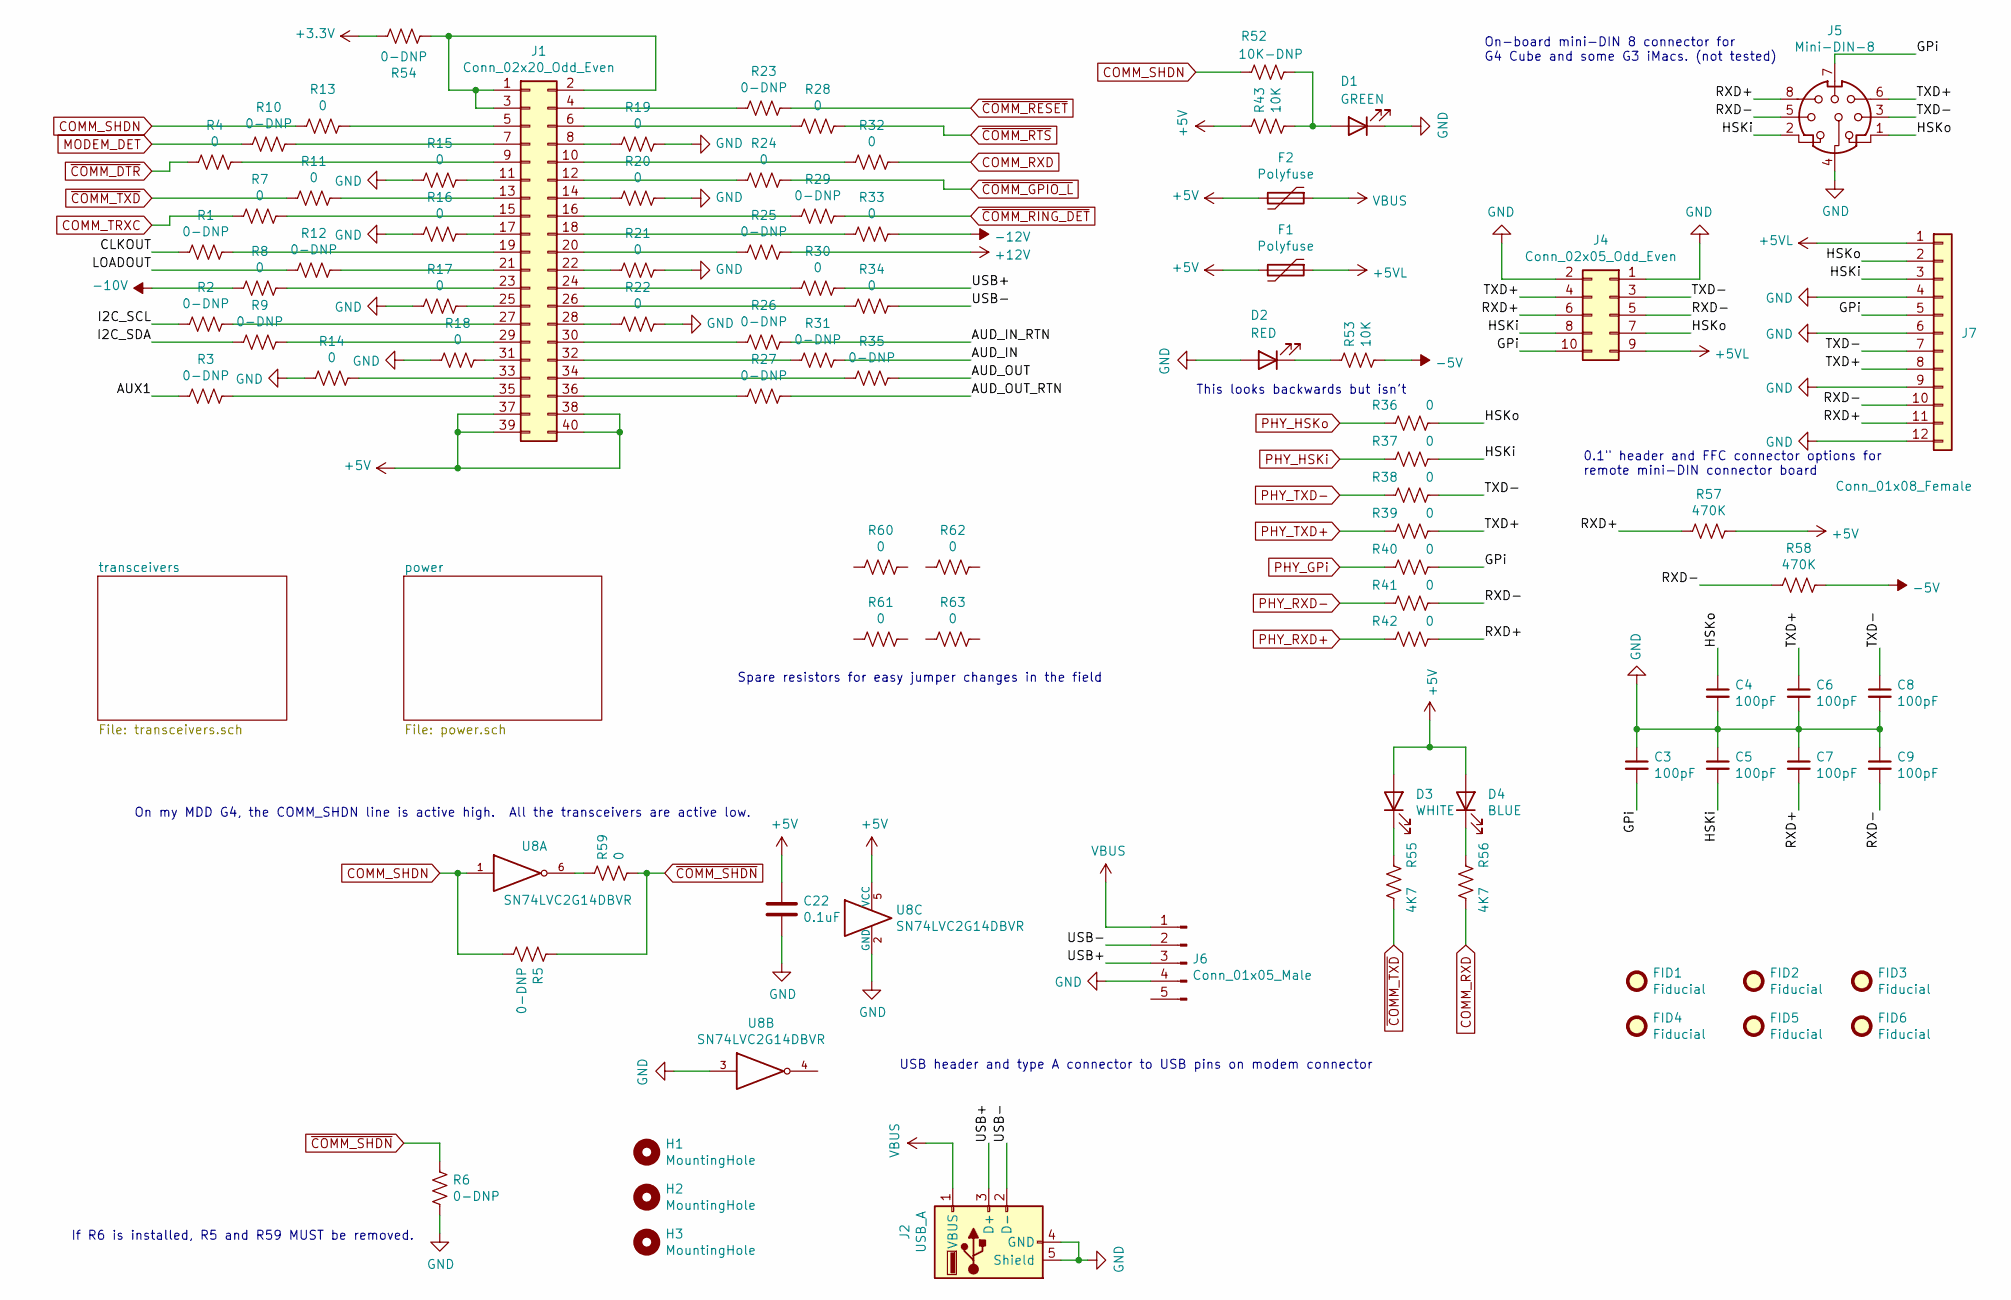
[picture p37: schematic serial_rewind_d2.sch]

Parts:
C3, C4, C5, C6, C7, C8, C9: 100pF; C_0603_1608Metric_Pad1.08x0.95mm_HandSolder; JLCPCB C14858
C22: 0.1uF; C_0603_1608Metric_Pad1.08x0.95mm_HandSolder; JLCPCB C14663
D1: GREEN; LED_0805_2012Metric; JLCPCB C2297
D2: RED; LED_0805_2012Metric; JLCPCB C84256
D3: WHITE; LED_0805_2012Metric; JLCPCB C34499
D4: BLUE; LED_0805_2012Metric; JLCPCB C2293
F1, F2: Polyfuse; Fuse_0805_2012Metric_Pad1.15x1.40mm_HandSolder; JLCPCB C70057
FID1, FID2, FID3, FID4, FID5, FID6: Fiducial; Fiducial_1mm_Mask2mm
H1, H2, H3: MountingHole; MountingHole_3.2mm_M3_Pad
J1: Conn_02x20_Odd_Even; 0528850474; Digikey WM3397CT-ND
J2: USB_A; USB_A_HORIZ_VERT_COMBO
J4: Conn_02x05_Odd_Even; PinHeader_2x05_P2.54mm_Vertical; Digikey 2057-PH2-10-UA-ND
J5: Mini-DIN-8; MINI_DIN8; Digikey 2057-MDJ-008-FS-ND
J6: Conn_01x05_Male; PinSocket_1x05_P2.54mm_Vertical
J7: Conn_01x08_Female; Hirose_FH12-12S-0.5SH_1x12-1MP_P0.50mm_Horizontal
R1, R2, R3, R5, R6, R9, R10, R12, R23, R25, R26, R27, R29, R31, R35, R54: 0-DNP; R_0603_1608Metric_Pad0.98x0.95mm_HandSolder; Digikey RMCF0603ZT0R00CT-ND
R4, R7, R8, R11, R13, R14, R15, R16, R17, R18, R19, R20, R21, R22, R24, R28, R30, R32, R33, R34, R36, R37, R38, R39, R40, R41, R42, R60, R61, R62, R63: 0; R_0603_1608Metric_Pad0.98x0.95mm_HandSolder; JLCPCB C21189
R43, R53: 10K; R_0603_1608Metric_Pad0.98x0.95mm_HandSolder; JLCPCB C25804
R52: 10K-DNP; R_0603_1608Metric_Pad0.98x0.95mm_HandSolder; Digikey RMCF0603JT10K0CT-ND
R55, R56: 4K7; R_0603_1608Metric_Pad0.98x0.95mm_HandSolder; JLCPCB C23162
R57, R58: 470K; R_0603_1608Metric_Pad0.98x0.95mm_HandSolder; Digikey RMCF0603FT470KCT-ND
R59: 0; R_0603_1608Metric_Pad0.98x0.95mm_HandSolder; Digikey RMCF0603ZT0R00CT-ND
U8: SN74LVC2G14DBVR; SOT-23-6_Handsoldering; Digikey 296-13010-1-ND

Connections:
+3V3: R54.1
+5V: C22.1, D3.2 (A), D4.2 (A), F1.2, F2.2, J1.37, J1.38, J1.39, J1.40, R43.1, R57.1, U8.5 (VCC); also elsewhere on the board
+5VL: F1.1, J4.9, J7.1
+12V: R25.1
-5V: R53.2, R58.1; also elsewhere on the board
-10V: R8.2; also elsewhere on the board
-12V: R33.1; also elsewhere on the board
/AUD_IN: R31.1
/AUD_IN_RTN: R26.1
/AUD_OUT: R35.1
/AUD_OUT_RTN: R27.1
/AUX1: R3.2
/CLKOUT: R1.2
/GPi: C3.2, J4.10, J5.7, J7.5, R40.1
/HSKi: C5.2, J4.8, J5.2, J7.3, R37.1
/HSKo: C4.1, J4.7, J5.1, J7.2, R36.1
/I2C_SCL: R2.2
/I2C_SDA: R9.2
/LOADOUT: R12.2
/RXD+: C7.2, J4.6, J5.8, J7.11, R42.1, R57.2
/RXD-: C9.2, J4.5, J5.5, J7.10, R41.1, R58.2
/TXD+: C6.1, J4.4, J5.6, J7.8, R39.1
/TXD-: C8.1, J4.3, J5.3, J7.7, R38.1
/USB+: J2.3 (D+), J6.3, R30.1
/USB-: J2.2 (D-), J6.2, R34.1
COMM_RXD: R32.1, R56.1; also elsewhere on the board
COMM_SHDN: R5.1, R13.2, R52.1, U8.1; also elsewhere on the board
COMM_TRXC: R7.2; also elsewhere on the board
GND: C3.1, C4.2, C5.1, C6.2, C7.1, C8.2, C9.1, C22.2, D1.1 (K), D2.2 (A), J2.4 (GND), J2.5 (Shield), J4.1, J4.2, J5.4, J6.4, J7.4, J7.6, J7.9, J7.12, R6.1, R14.2, R15.2, R16.2, R17.2, R18.2, R19.1, R20.1, R21.1, R22.1, U8.2 (GND), U8.3; also elsewhere on the board
MODEM_DET: R10.2
unnamed: D1.2 (A), R43.2, R52.2
unnamed: D2.1 (K), R53.1
unnamed: D3.1 (K), R55.2
unnamed: D4.1 (K), R56.2
unnamed: J1.1, J1.2, J1.3, R54.2
unnamed: J1.4, R23.2
unnamed: J1.5, R13.1
unnamed: J1.6, R28.2
unnamed: J1.7, R10.1
unnamed: J1.8, R19.2
unnamed: J1.9, R4.1
unnamed: J1.10, R32.2
unnamed: J1.11, R15.1
unnamed: J1.12, R24.2
unnamed: J1.13, R11.1
unnamed: J1.14, R20.2
unnamed: J1.15, R7.1
unnamed: J1.16, R29.2
unnamed: J1.17, R16.1
unnamed: J1.18, R33.2
unnamed: J1.19, R1.1
unnamed: J1.20, R25.2
unnamed: J1.21, R12.1
unnamed: J1.22, R21.2
unnamed: J1.23, R8.1
unnamed: J1.24, R30.2
unnamed: J1.25, R17.1
unnamed: J1.26, R34.2
unnamed: J1.27, R2.1
unnamed: J1.28, R22.2
unnamed: J1.29, R9.1
unnamed: J1.30, R26.2
unnamed: J1.31, R18.1
unnamed: J1.32, R31.2
unnamed: J1.33, R14.1
unnamed: J1.34, R35.2
unnamed: J1.35, R3.1
unnamed: J1.36, R27.2
unnamed: R59.2, U8.6
PHY_GPi: R40.2; also elsewhere on the board
PHY_HSKi: R37.2; also elsewhere on the board
PHY_HSKo: R36.2; also elsewhere on the board
PHY_RXD+: R42.2; also elsewhere on the board
PHY_RXD-: R41.2; also elsewhere on the board
PHY_TXD+: R39.2; also elsewhere on the board
PHY_TXD-: R38.2; also elsewhere on the board
VBUS: F2.1, J2.1 (VBUS), J6.1
~COMM_DTR: R4.2; also elsewhere on the board
~COMM_GPIO_L: R24.1; also elsewhere on the board
~COMM_RESET: R23.1
~COMM_RING_DET: R29.1
~COMM_RTS: R28.1; also elsewhere on the board
~COMM_SHDN: R5.2, R6.2, R59.1; also elsewhere on the board
~COMM_TXD: R11.2, R55.1; also elsewhere on the board

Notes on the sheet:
On-board mini-DIN 8 connector for G4 Cube and some G3 iMacs. (not tested)
0.1" header and FFC connector options for remote mini-DIN connector board
If R6 is installed, R5 and R59 MUST be removed.
USB header and type A connector to USB pins on modem connector
This looks backwards but isn't
On my MDD G4, the COMM_SHDN line is active high. All the transceivers are active low.
Spare resistors for easy jumper changes in the field

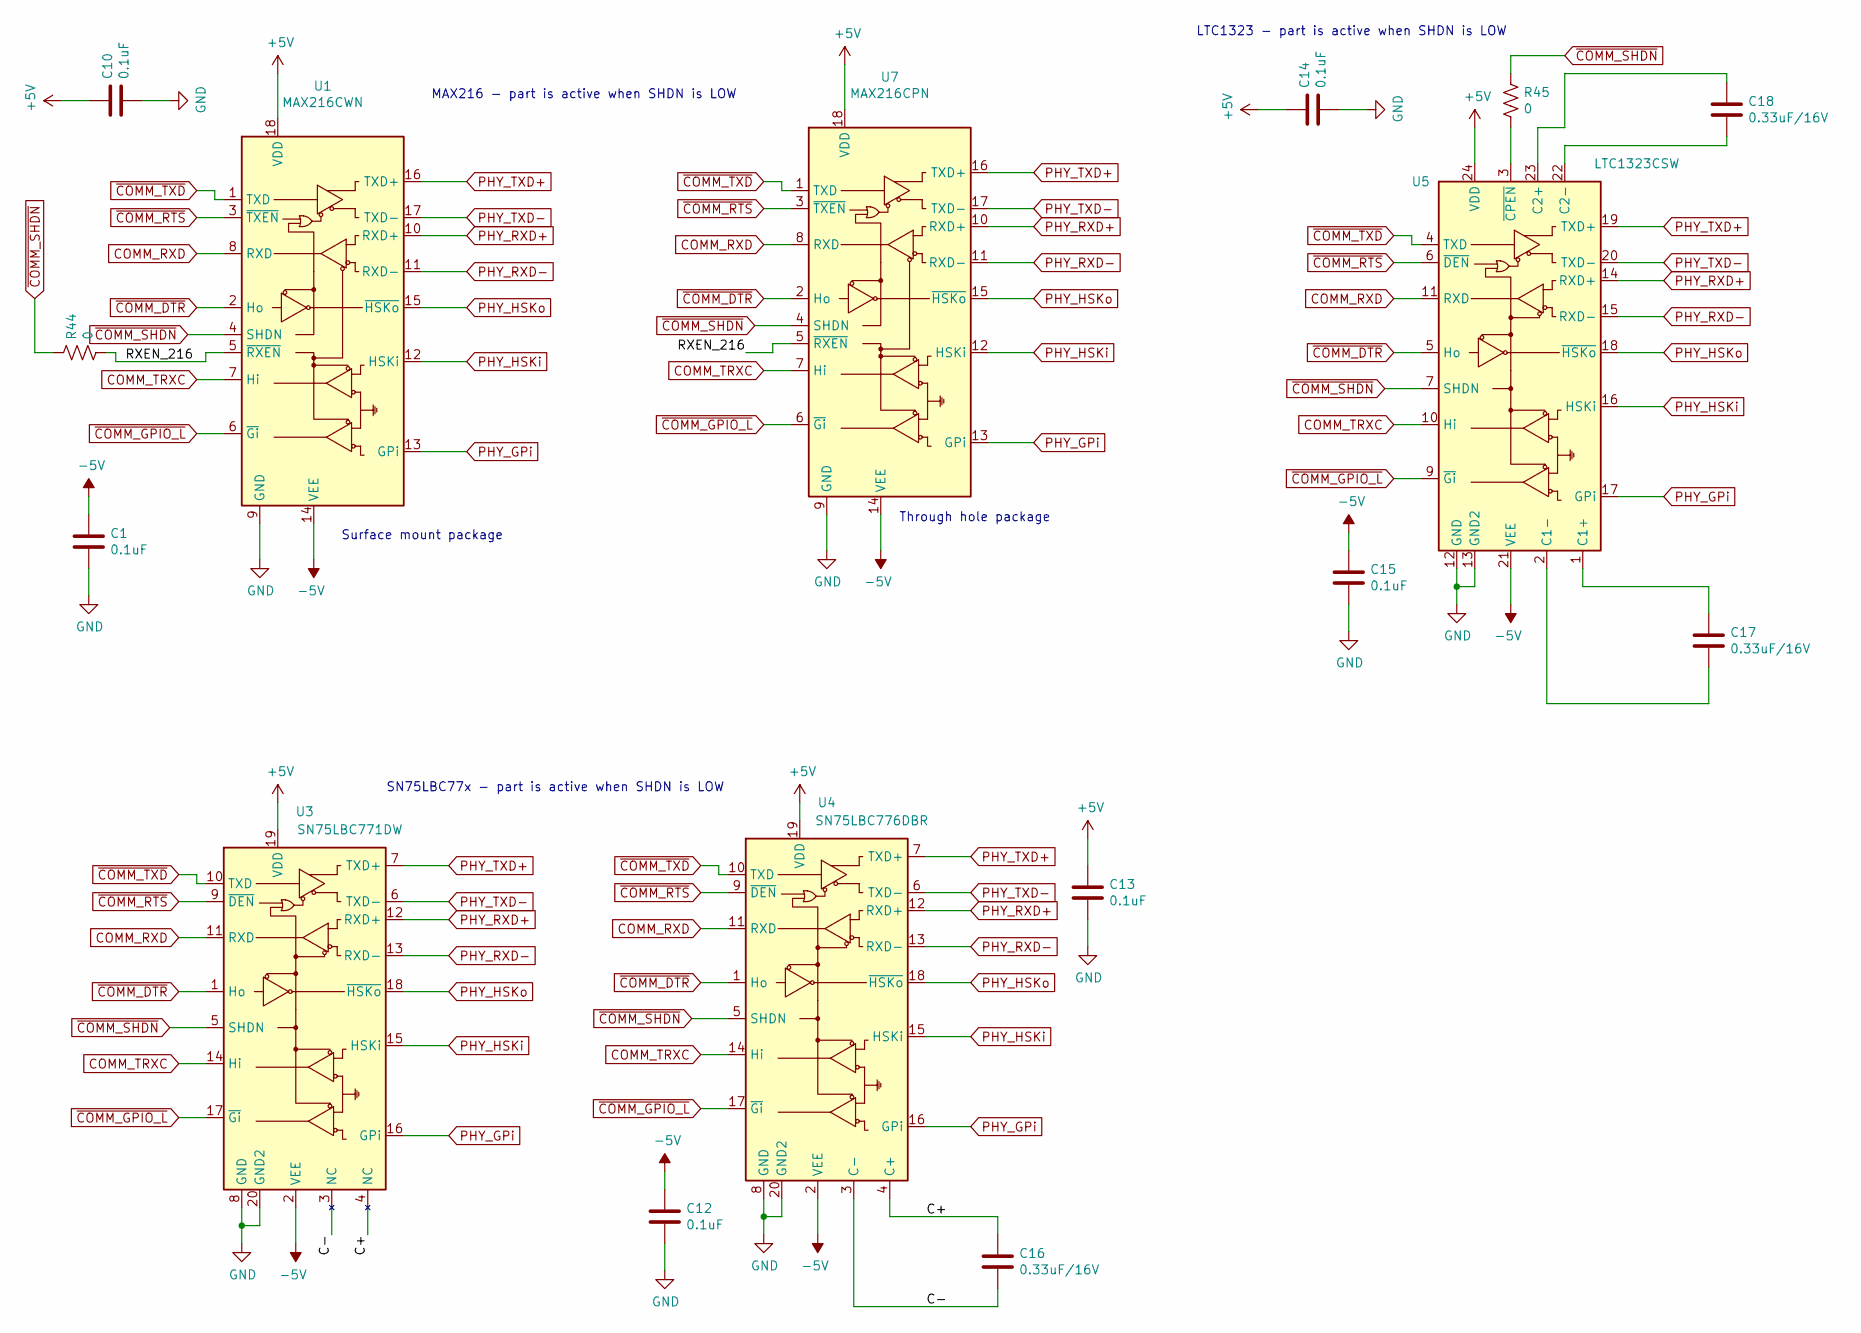
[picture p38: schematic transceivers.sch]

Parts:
C1, C10, C12, C13, C14, C15: 0.1uF; C_0603_1608Metric_Pad1.08x0.95mm_HandSolder; JLCPCB C14663
C16, C17, C18: 0.33uF/16V; C_0805_2012Metric_Pad1.18x1.45mm_HandSolder; JLCPCB C1740
R44, R45: 0; R_0603_1608Metric_Pad0.98x0.95mm_HandSolder; JLCPCB C21189
U1: MAX216CWN; SOIC-18W_7.5x11.6mm_P1.27mm; Digikey MAX216CWN+-ND
U3: SN75LBC771DW; SOP-20_7.5x12.8mm_P1.27mm
U4: SN75LBC776DBR; SSOP-20_5.3x7.2mm_P0.65mm
U5: LTC1323CSW; SOP-24_7.5x15.4mm_P1.27mm
U7: MAX216CPN; DIP-18_W7.62mm

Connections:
+5V: C10.1, C13.1, C14.1, U1.18 (VDD), U3.19 (VDD), U4.19 (VDD), U5.24 (VDD), U7.18 (VDD); also elsewhere on the board
-5V: C1.1, C12.1, C15.1, U1.14 (VEE), U3.2 (VEE), U4.2 (VEE), U5.21 (VEE), U7.14 (VEE); also elsewhere on the board
/transceivers/C+: C16.1, U3.4 (NC), U4.4 (C+)
/transceivers/C-: C16.2, U3.3 (NC), U4.3 (C-)
/transceivers/RXEN_216: R44.1, U1.5 (~RXEN), U7.5 (~RXEN)
COMM_RXD: U1.8 (RXD), U3.11 (RXD), U4.11 (RXD), U5.11 (RXD), U7.8 (RXD); also elsewhere on the board
COMM_TRXC: U1.7 (Hi), U3.14 (Hi), U4.14 (Hi), U5.10 (Hi), U7.7 (Hi); also elsewhere on the board
GND: C1.2, C10.2, C12.2, C13.2, C14.2, C15.2, U1.9 (GND), U3.8 (GND), U3.20 (GND2), U4.8 (GND), U4.20 (GND2), U5.12 (GND), U5.13 (GND2), U7.9 (GND); also elsewhere on the board
unnamed: C17.1, U5.1 (C1+)
unnamed: C17.2, U5.2 (C1-)
unnamed: C18.1, U5.23 (C2+)
unnamed: C18.2, U5.22 (C2-)
unnamed: R45.1, U5.3 (~CPEN)
PHY_GPi: U1.13 (GPi), U3.16 (GPi), U4.16 (GPi), U5.17 (GPi), U7.13 (GPi); also elsewhere on the board
PHY_HSKi: U1.12 (HSKi), U3.15 (HSKi), U4.15 (HSKi), U5.16 (HSKi), U7.12 (HSKi); also elsewhere on the board
PHY_HSKo: U1.15 (~HSKo), U3.18 (~HSKo), U4.18 (~HSKo), U5.18 (~HSKo), U7.15 (~HSKo); also elsewhere on the board
PHY_RXD+: U1.10 (RXD+), U3.12 (RXD+), U4.12 (RXD+), U5.14 (RXD+), U7.10 (RXD+); also elsewhere on the board
PHY_RXD-: U1.11 (RXD-), U3.13 (RXD-), U4.13 (RXD-), U5.15 (RXD-), U7.11 (RXD-); also elsewhere on the board
PHY_TXD+: U1.16 (TXD+), U3.7 (TXD+), U4.7 (TXD+), U5.19 (TXD+), U7.16 (TXD+); also elsewhere on the board
PHY_TXD-: U1.17 (TXD-), U3.6 (TXD-), U4.6 (TXD-), U5.20 (TXD-), U7.17 (TXD-); also elsewhere on the board
~COMM_DTR: U1.2 (Ho), U3.1 (Ho), U4.1 (Ho), U5.5 (Ho), U7.2 (Ho); also elsewhere on the board
~COMM_GPIO_L: U1.6 (~Gi), U3.17 (~Gi), U4.17 (~Gi), U5.9 (~Gi), U7.6 (~Gi); also elsewhere on the board
~COMM_RTS: U1.3 (~TXEN), U3.9 (~DEN), U4.9 (~DEN), U5.6 (~DEN), U7.3 (~TXEN); also elsewhere on the board
~COMM_SHDN: R44.2, R45.2, U1.4 (SHDN), U3.5 (SHDN), U4.5 (SHDN), U5.7 (SHDN), U7.4 (SHDN); also elsewhere on the board
~COMM_TXD: U1.1 (TXD), U3.10 (TXD), U4.10 (TXD), U5.4 (TXD), U7.1 (TXD); also elsewhere on the board

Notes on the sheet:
Surface mount package
Through hole package
MAX216 - part is active when SHDN is LOW
LTC1323 - part is active when SHDN is LOW
SN75LBC77x - part is active when SHDN is LOW

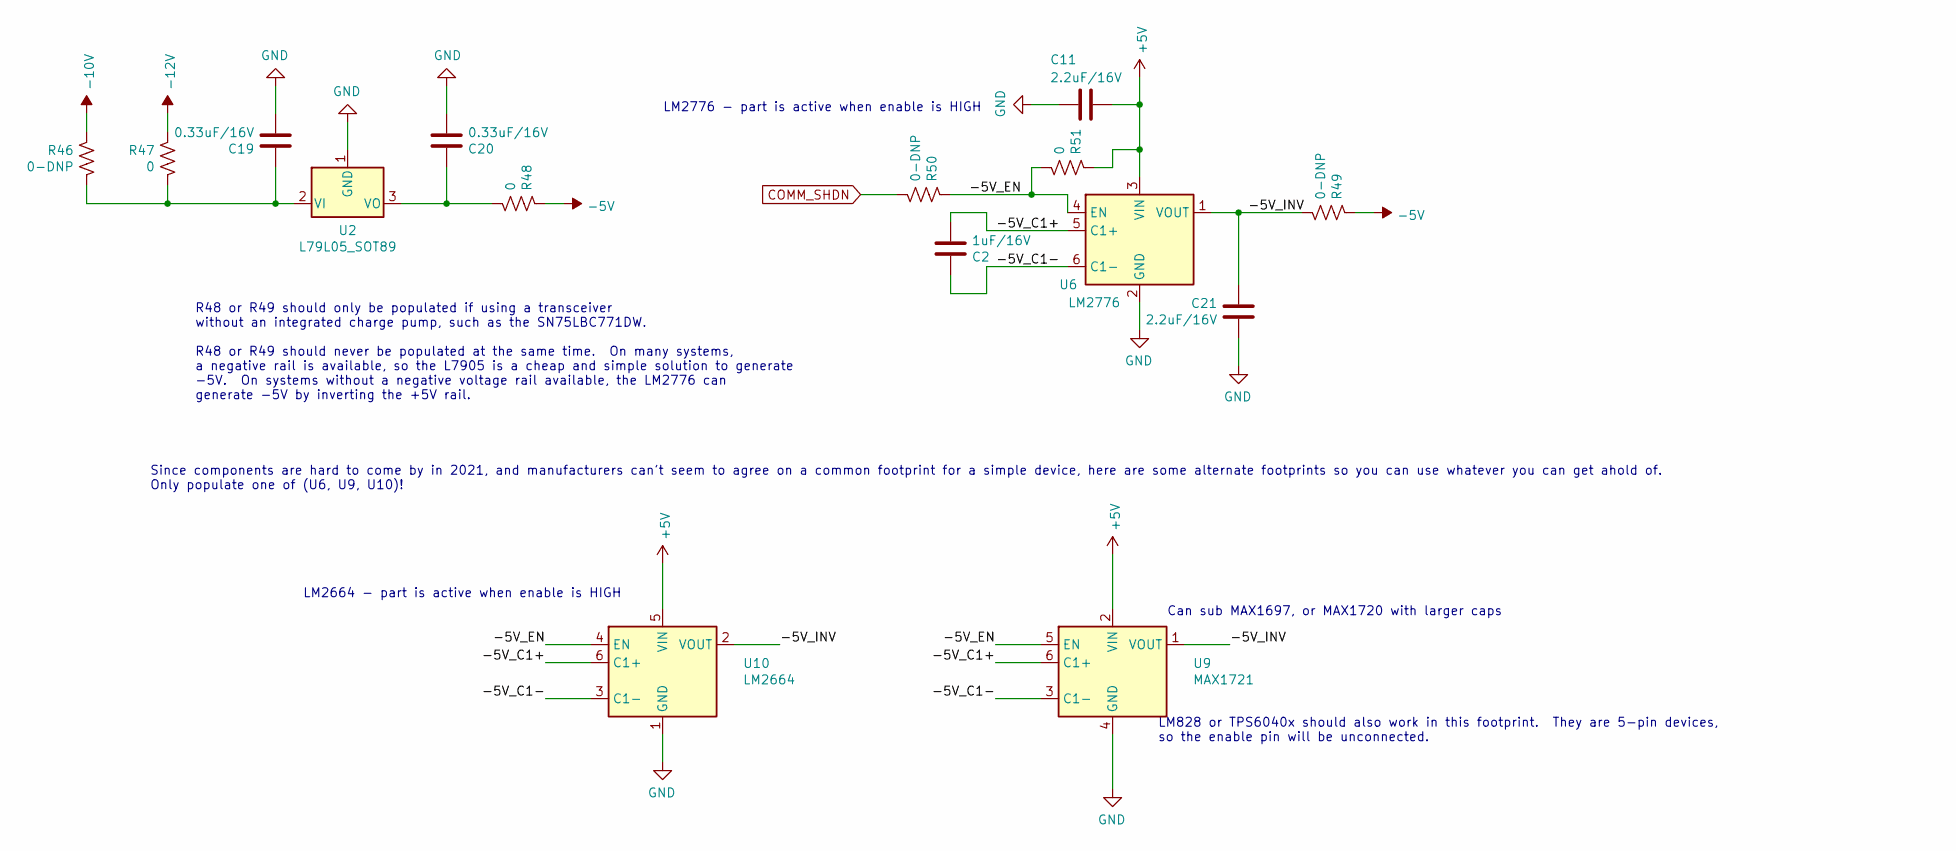
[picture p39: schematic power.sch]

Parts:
C2: 1uF/16V; C_0805_2012Metric_Pad1.18x1.45mm_HandSolder; JLCPCB C28323
C11, C21: 2.2uF/16V; C_0805_2012Metric_Pad1.18x1.45mm_HandSolder; JLCPCB C49217
C19, C20: 0.33uF/16V; C_0805_2012Metric_Pad1.18x1.45mm_HandSolder; JLCPCB C1740
R46, R49, R50: 0-DNP; R_0603_1608Metric_Pad0.98x0.95mm_HandSolder; Digikey RMCF0603ZT0R00CT-ND
R47: 0; R_0603_1608Metric_Pad0.98x0.95mm_HandSolder; Digikey RMCF0603ZT0R00CT-ND
R48, R51: 0; R_0603_1608Metric_Pad0.98x0.95mm_HandSolder; JLCPCB C21189
U2: L79L05_SOT89; SOT-89-3; JLCPCB DNP-C842820
U6: LM2776; SOT-23-6_Handsoldering; JLCPCB C840110
U9: MAX1721; SOT-23-6_Handsoldering; JLCPCB C242523
U10: LM2664; SOT-23-6_Handsoldering; JLCPCB C840095

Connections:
+5V: C11.1, R51.2, U6.3 (VIN), U9.2 (VIN), U10.5 (VIN); also elsewhere on the board
-5V: R48.2, R49.2; also elsewhere on the board
-10V: R46.2; also elsewhere on the board
-12V: R47.2; also elsewhere on the board
/power/-5V_C1+: C2.2, U6.5 (C1+), U9.6 (C1+), U10.6 (C1+)
/power/-5V_C1-: C2.1, U6.6 (C1-), U9.3 (C1-), U10.3 (C1-)
/power/-5V_EN: R50.2, R51.1, U6.4 (EN), U9.5 (EN), U10.4 (EN)
/power/-5V_INV: C21.1, R49.1, U6.1 (VOUT), U9.1 (VOUT), U10.2 (VOUT)
COMM_SHDN: R50.1; also elsewhere on the board
GND: C11.2, C19.2, C20.2, C21.2, U2.1 (GND), U6.2 (GND), U9.4 (GND), U10.1 (GND); also elsewhere on the board
unnamed: C19.1, R46.1, R47.1, U2.2 (VI)
unnamed: C20.1, R48.1, U2.3 (VO)

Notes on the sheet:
R48 or R49 should only be populated if using a transceiver without an integrated charge pump, such as the SN75LBC771DW. R48 or R49 should never be populated at the same time. On many systems, a negative rail is available, so the L7905 is a cheap and simple solution to generate -5V. On systems witho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
LM2776 - part is active when enable is HIGH
Can sub MAX1697, or MAX1720 with larger caps
Since components are hard to come by in 2021, and manufacturers can't seem to agree on a common footprint for a simple device, here are some alternate footprints so you can use whatever you can get ahold of. Only populate one of (U6, U9, U10)!
LM828 or TPS6040x should also work in this footprint. They are 5-pin devices, so the enable pin will be unconnected.
LM2664 - part is active when enable is HIGH

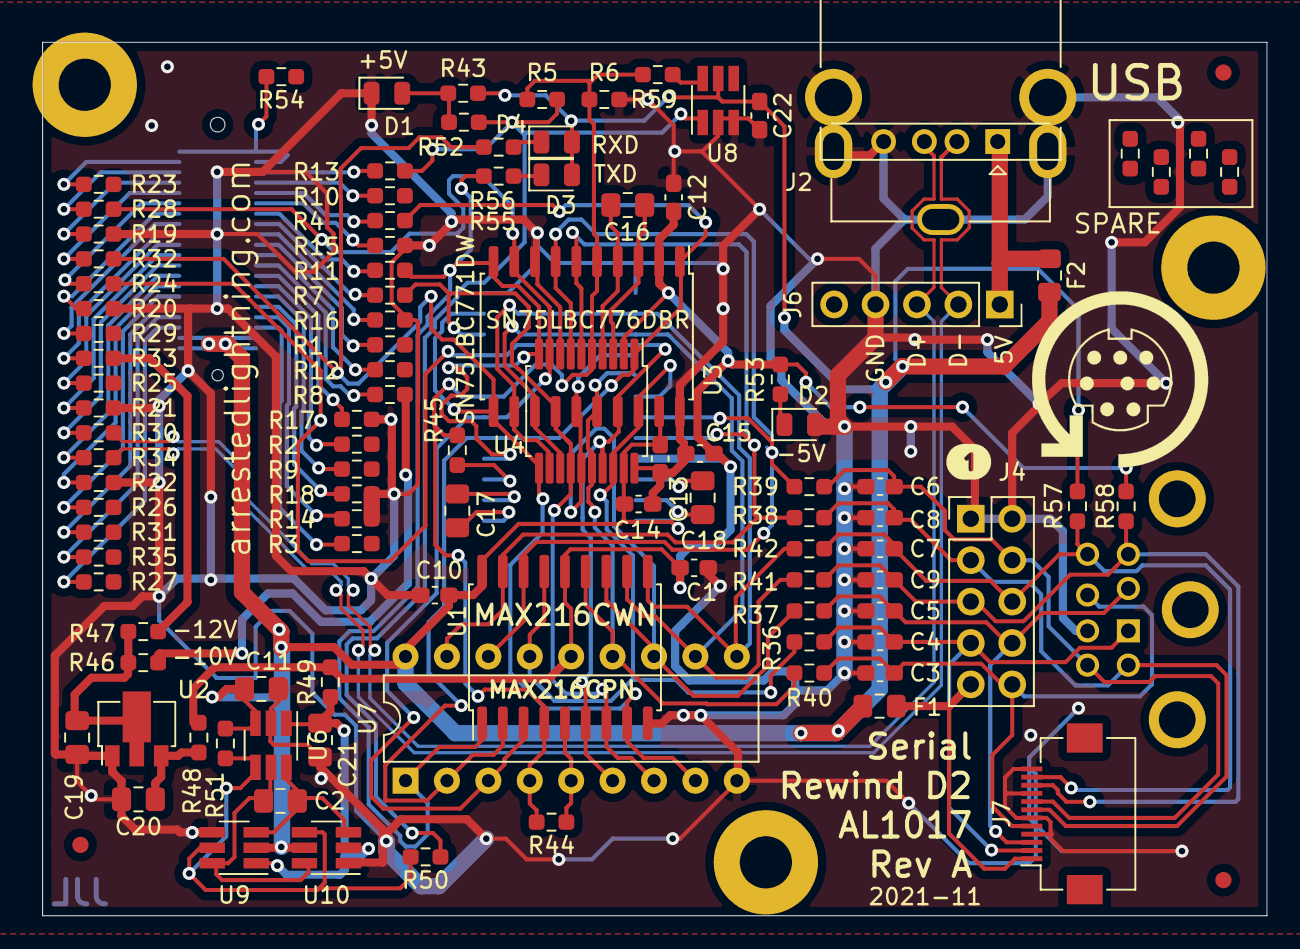
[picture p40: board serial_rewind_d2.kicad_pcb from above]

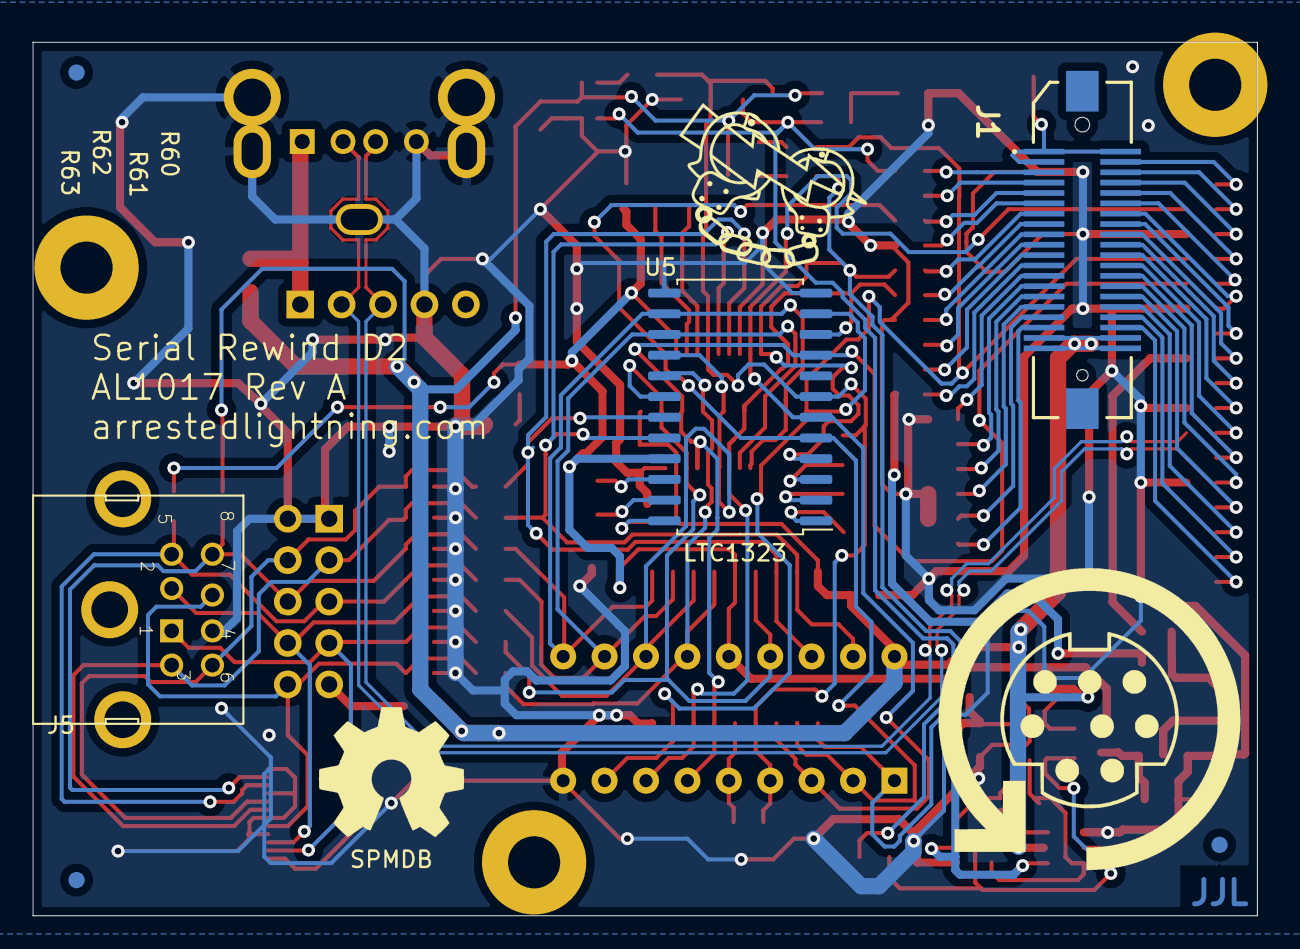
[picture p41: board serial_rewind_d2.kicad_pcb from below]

Board: 2 copper layers, 75.1 x 53.6 mm, 117 parts (6 on the bottom side), 84 nets.

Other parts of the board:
kibuzzard-619185EE: G***; label

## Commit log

2022-06-19 Added latest hardware files.
    [Board Outline-BodySketch.dxf, Board Outline.FCStd, Mounting Face.FCStd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]
2022-06-19 Added README files for each board.
